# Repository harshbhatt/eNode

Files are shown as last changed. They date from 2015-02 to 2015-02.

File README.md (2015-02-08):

# Notes
* Some resistors and capacitors (imported from the photon) don't have a "box" silkscreen in their footprint - for the final batch, these footprints are better omitted.
* RF components have been placed using the photon as reference
  * (X,Y) coords for RF components have been taken from reference design then moved as a group to maintain relative positioning
* (X,Y) coords for the remaining major components can be referenced from V2
* Make sure to use the 4-layer DRC from spark (under photon\cam-drc\spark-4layer.dru)
* Keep all traces at **12mils** unless absolutely needed

# To-Do
* Change MEMs mic to Condenser mic
* Ground plane vias for RF
* Determine good location for RGB LED
* Copy keepout & fill polygons from V2.2 and photon reference
* Source a SMT LDR?
* All remaining RLC footprints can be replaced with the footprints used by spark, or the master library can be updated

* Possibly shorten overall length of sensor -> if all components fit

# General Guide
* Don't commit library, board and schematic backup files auto generated by Eagle (should be taken care of, by the included .gitignore file, but just fyi)
* Look at V2.2 & photon for reference (Under reference drawings folder)
* Make sure you set your library path to the `Libraries` folder under `Options->Directories` in Eagle

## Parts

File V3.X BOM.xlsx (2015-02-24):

Revision: 3.0 | Project: SenSing V3.1 | Date Revised: | 2015-02-20
Sub-System | Description & Link | Designator | Package / Case | Value & Tol | Manufacturer | Manufacturer P/N | Supplier | Supplier Code | Units /Piece | Unit Price | Total Price /Piece | Total Quantity | Total Price | Notes
Power & Charging | 1800 mAh Li-Po Battery (https://www.sparkfun.com/products/12895) |  |  |  |  |  | Data Power |  | 1 | $2.700 | $2.70 | 80000 | $216000.00 | USD Conv.
 | 3.3v LDO (http://sg.element14.com/richtek/rt9183-33gg/ic-ldo-fixed-3-3v-1-5a-sot-223/dp/2363116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) |  |  |  |  |  | Element14 | 2363116 | 1 | $0.380 | $0.38 | 80000 | $30400.00
 | MCP73831T (Charging) (http://sg.element14.com/jsp/search/productdetail.jsp?id=1332158) |  |  |  |  |  |  |  | 1 | $0.430 | $0.43 | 80000 | $34400.00
 | Micro USB (http://sg.element14.com/jsp/search/productdetail.jsp?SKU=1568026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) |  |  |  |  |  | Element14 | 1568026 | 0 | $0.693 | $0.00 | 0 | $0.00
 | ALT SMD Micro USB (http://sg.element14.com/webapp/wcs/stores/servlet/ProductDisplay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) |  |  |  |  |  | Element14 | 1847433 | 1 | $0.685 | $0.69 | 80000 | $54800.00
 | 4.7 uF (http://sg.element14.com/murata/grm155r60j475me47d/cap-mlcc-x5r-4-7uf-6-3v-0402/dp/2426952) |  | 402 |  |  |  | Element14 | 2426952 | 2 | $0.169 | $0.34 | 160000 | $27040.00
 | 2K OHM (http://sg.element14.com/vishay-draloric/crcw06032k00fkea/product-range-vishay-crcw-series/dp/1469764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) |  | 603 |  |  |  | Element14 | 1469764 | 1 | $0.009 | $0.01 | 80000 | $720.00
 | 100 OHM (http://sg.element14.com/yageo-phycomp/rc0603jr-07100rl/resistor-rc21-0603-100r/dp/9233253) |  | 603 |  |  |  | Element14 | 9233253 | 1 | $0.001 | $0.001 | 80000 | $80.00
 | Indicator LED SMT (http://sg.element14.com/kingbright/ka-2810asursk/led-smd-2-8-x-0-8mm-side-view-red/dp/2146470) |  |  |  |  |  | Element14 | 2146470 | 1 | $0.297 | $0.30 | 80000 | $23760.00
 | JST Header 2-way SMT (http://sg.element14.com/jst-japan-solderless-terminals/s2b-ph-sm4-tb-lf-sn/connector-header-smt-r-a-2mm-2way/dp/9492615) |  |  |  |  |  | Element14 | 9492615 | 1 | $0.832 | $0.83 | 80000 | $66560.00
 |  |  |  |  |  |  |  |  |  |  |  | 0
Current Sensor | INA 219 (http://www.digikey.sg/product-detail/en/INA219AIDCNR/296-23770-1-ND/1952550) |  |  |  |  |  |  |  | 1 | $0.860 | $0.86 | 80000 | $68800.00
 | 0.1 uF (0402) (http://sg.element14.com/multicomp/mc0402x104k100ct/cap-mlcc-x5r-100nf-10v-0402/dp/1759380RL) |  | 402 |  |  |  | Element14 | 1759380RL | 1 | $0.003 | $0.003 | 80000 | $240.00
 | 0.1ohm 1 % (http://www.digikey.sg/product-detail/en/PT2512FK-070R1L/311-0.1ARDKR-ND/2178416) |  | 2512 |  |  |  | Digikey | 311-0.1ARDKR-ND | 0 | $0.440 | $0.00 | 0 | $0.00
 | 0.1 OHM 1% (http://sg.element14.com/panasonic-electronic-components/erj1trsfr10u/resistor-2512-1w-1-0r1/dp/1717945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) |  | 2512 |  |  |  | Element14 | 1717945 | 1 | $0.341 | $0.34 | 80000 | $27280.00
Main PCB components | BM-09 (http://sg.element14.com/jsp/search/productdetail.jsp?sku=1469748RL) |  |  |  |  |  | EDOM/USI |  | 1 | $8.910 | $8.91 | 80000 | $712800.00 | USD Conv.
 | 10K OHM 1% (http://sg.element14.com/jsp/search/productdetail.jsp?sku=1469748RL) |  | 603 |  |  |  | Element14 | 1469748RL | 2 | $0.004 | $0.01 | 160000 | $640.00
 | User Button (http://sg.element14.com/te-connectivity-alcoswitch/fsm4jsmatr/switch-tactile-spst-50ma-smd-outside/dp/2410652) |  |  |  |  |  | Element14 | 2410652 | 2 | $0.183 | $0.37 | 160000 | $29280.00
 | Mode & Reset Button (http://sg.element14.com/multicomp/dtsm-32s-b/switch-spno-0-05a-12v-smd/dp/9471898?ost=DTSM-3) |  |  |  |  |  | Element14 | 9471898 | 2 | $0.254 | $0.51 | 160000 | $40640.00
 | Switch (http://sg.element14.com/eao/09-10290-01/switch-slide-spdt-co-500ma-thd/dp/674357) |  |  |  |  |  | Element14 | 1634623 | 1 | $2.150 | $2.15 | 80000 | $172000.00
 | 4.7K OHM 1% (http://sg.element14.com/multicomp/mc00625w040214k7/resistor-4k7-0-063w-1-0402/dp/1358060) |  | 402 |  |  |  | Element14 | 1358060 | 2 | $0.002 | $0.004 | 160000 | $320.00
 | RGB LED (http://sg.element14.com/cree/clv1l-fkb-chmmqehbb7673673/led-red-green-blue-plcc-4/dp/2414451) |  |  |  |  |  | Element14 | 2414451 | 1 | $0.300 | $0.30 | 80000 | $24000.00
 | Chip Antenna (http://www.digikey.sg/product-detail/en/2450AT43B100E/712-1010-2-ND/1560681) |  |  |  |  |  | Digikey | 712-1010-2-ND | 1 | $0.331 | $0.33 | 80000 | $26462.40
 | 0.8pF RF CAP (http://www.digikey.sg/product-detail/en/GJM1555C1HR80BB01D/490-6080-2-ND/2593264) |  |  |  |  |  | Digikey | 490-6080-2-ND | 1 | $0.034 | $0.03 | 80000 | $2685.60
 | 3.3nH RF IND |  |  |  |  |  | MFG: Hong Kong SUNLORD Co.,Ltd. | PN: HCI1005F-3N3J | 1 |  | $0.00 | 80000 | $0.00
 | 1K OHM (http://sg.element14.com/multicomp/mc00625w040211k/resistor-1k-0-063w-1-0402-reel/dp/2130354) |  |  |  |  |  | Element14 | 2130354 | 4 | $0.002 | $0.01 | 320000 | $576.00
 |  |  |  |  |  |  |  |  |  |  |  | 0
SD | Micro SD Card Slot (http://sg.element14.com/global-connector-technology/mem2051-00-195-00-a/connector-memory-card-micro-sd/dp/2143377) |  |  |  |  |  |  |  | 1 | $0.550 | $0.55 | 80000 | $44000.00
 | Micro SD Card 8GB |  |  |  |  |  | Local Shop |  | 1 | $5.000 | $5.00 | 80000 | $400000.00
IMU | MPU 9150 |  |  |  |  |  |  |  | 1 | $4.710 | $4.71 | 80000 | $376800.00
 | 0.1 uF (0402) (http://sg.element14.com/multicomp/mc0402x104k100ct/cap-mlcc-x5r-100nf-10v-0402/dp/1759380RL) |  | 402 |  |  |  | Element14 | 1759380RL | 2 | $0.003 | $0.01 | 160000 | $480.00
 | 10nF (0.01uF) (http://sg.element14.com/tdk/c1005x7r1e103k050bb/capacitor-ceramic-0-01uf-25v-x7r/dp/1844133?Ntt=1844133) |  | 402 |  |  |  | Element14 | 1844133 | 1 | $0.065 | $0.07 | 80000 | $5200.00
 | 2.2nF (2200pF) (http://sg.element14.com/murata/grm155r71h222ka01d/cap-mlcc-x7r-2-2nf-50v-0402/dp/1828884) |  | 402 |  |  |  | Element14 | 1828884 | 1 | $0.010 | $0.01 | 80000 | $800.00
 |  |  |  |  |  |  |  |  |  |  |  | 0
LDR | LDR - Alt (http://www.digikey.sg/product-search/en?k=+Photo+Light+Dependent+Resistors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) |  |  |  |  |  | Digikey |  | 1 | $0.488 | $0.49 | 80000 | $39040.00
 | 10K OHM 1% (http://sg.element14.com/jsp/search/productdetail.jsp?sku=1469748RL) |  | 603 |  |  |  | Element14 | 1469748RL | 1 | $0.004 | $0.004 | 80000 | $320.00
Mic | Electret Mic |  |  |  | Challenge Electronics | CEM-C9745JAD462P2.54R | Sparkfun | COM-08635 | 1 | $0.675 | $0.68 | 80000 | $54000.00 | Usd Conv. - Changed from MEMs to electret condenser MIC - Calibration tool: http://www.ebay.ca/itm/Mini-Digital-LCD-Audio-Sound-Noise-Level-Meter-Tester-30-130dB-Decibel-Pressure-/271660773561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 - Double check alt sensitivity before using
 | Electret Mic Alt (http://www.digikey.sg/product-detail/en/CMA-4544PF-W/102-1721-ND/1869981) |  |  |  |  |  | Digikey | 102-1721-ND | 0 | $1.340 | $0.00 | 0 | $0.00
 | OPA344 Opamp (http://sg.element14.com/texas-instruments/opa344na-250/ic-op-amp-1mhz-0-8v-us-sot-23-5/dp/9547550) |  |  |  |  |  | Element14 | 9547550 | 1 | $1.010 | $1.01 | 80000 | $80800.00
 | 10K OHM 1% (http://sg.element14.com/jsp/search/productdetail.jsp?sku=1469748RL) |  | 402 | 10K ±1% |  |  | Element14 | 1469748RL | 3 | $0.004 | $0.01 | 240000 | $960.00
 | 2.2K (Pull-Up) (http://sg.element14.com/yageo-phycomp/rc0402jr-072k2l/resistor-rc31-0402-2k2/dp/9232800RL) |  | 402 | 2.2K ±1% |  |  | Element14 | 9232800RL | 1 | $0.001 | $0.001 | 80000 | $80.00
 | 1M (http://sg.element14.com/susumu/rr1220p-105-d/resistor-thin-film-1mohm-100mw/dp/9369716) |  | 402 | 1M ±1% |  |  | Element14 | 9369716 | 1 | $0.014 | $0.01 | 80000 | $1120.00
 | 12pF (http://sg.element14.com/multicomp/mc0402n120k500ct/capacitor-ceramic-12pf-50v-c0g/dp/1709787) |  | 402 | 12pF ±5% |  |  | Element14 | 1709787 | 1 | $0.005 | $0.01 | 80000 | $400.00
 | 4.7 uF (http://sg.element14.com/murata/grm155r60j475me47d/cap-mlcc-x5r-4-7uf-6-3v-0402/dp/2426952) |  | 402 | 4.7uF ±10% |  |  | Element14 | 1759452 | 1 | $0.028 | $0.03 | 80000 | $2240.00
 | 1.0 uF (0603) (http://sg.element14.com/jsp/search/productdetail.jsp?sku=1288256) |  | 402 | 1.0uF ±10% |  |  | Element14 | 1288256 | 1 | $0.013 | $0.01 | 80000 | $1040.00
 | 0.1 uF (0402) (http://sg.element14.com/multicomp/mc0402x104k100ct/cap-mlcc-x5r-100nf-10v-0402/dp/1759380RL) |  | 402 | 0.1uF ±10% |  |  | Element14 | 1759380RL | 1 | $0.003 | $0.003 | 80000 | $240.00
Humidity & Temperature | HTU21D (http://sg.element14.com/measurement-specialties/htu21d/humidity-digital-3-rh-dfn-6/dp/2393536?Ntt=HTU21D) |  |  |  |  |  |  |  | 1 | $3.210 | $3.21 | 80000 | $256800.00
 | 0.1 uF (0402) (http://sg.element14.com/multicomp/mc0402x104k100ct/cap-mlcc-x5r-100nf-10v-0402/dp/1759380RL) |  | 402 |  |  |  | Element14 | 1759380RL | 1 | $0.003 | $0.003 | 80000 | $240.00
Barometer | BMP180 (http://www.mouser.sg/ProductDetail/Bosch-Sensortec/BMP180/?qs=sGAEpiMZZMsrChSOYEGTCcbpL13VfRyojs5HQb1tBiU%3d) |  |  |  |  |  |  | 262-BMP180 | 1 | $1.180 | $1.18 | 80000 | $94400.00
 | BMP180 Alt (https://www.sparkfun.com/products/11823) |  |  |  |  |  | Sparkfun |  | 0 | $6.683 | $0.00 | 0 | $0.00
 | 10uF Tant (http://sg.element14.com/jsp/search/productdetail.jsp?sku=2333009) |  | 1206 |  |  |  | Element14 | 2333009 | 1 | $0.379 | $0.38 | 80000 | $30320.00
 | 0.1 uF (0402) (http://sg.element14.com/multicomp/mc0402x104k100ct/cap-mlcc-x5r-100nf-10v-0402/dp/1759380RL) |  | 402 |  |  |  | Element14 | 1759380RL | 2 | $0.003 | $0.01 | 160000 | $480.00
 |  |  |  |  |  |  |  |  |  |  |  | 0
IR Temperature | TMP007 (http://www.digikey.sg/product-detail/en/TMP007AIYZFT/296-37914-1-ND/4900960) |  |  |  |  |  | Digikey | 296-28819-2-ND | 1 | $5.000 | $5.00 | 80000 | $400000.00
 | 10K OHM 1% (http://sg.element14.com/jsp/search/productdetail.jsp?sku=1469748RL) |  | 603 |  |  |  | Element14 | 1469748RL | 3 | $0.004 | $0.01 | 240000 | $960.00
 | 0.1 uF (0402) (http://sg.element14.com/multicomp/mc0402x104k100ct/cap-mlcc-x5r-100nf-10v-0402/dp/1759380RL) |  | 402 |  |  |  | Element14 | 1759380RL | 1 | $0.003 | $0.003 | 80000 | $240.00
 |  |  |  |  |  |  |  |  |  |  |  | 0
 |  |  |  |  |  |  |  |  |  |  |  | 0
Buzzer | 14mm DIA Buzzer |  |  |  |  |  | Adafruit |  | 1 | $1.282 | $1.28 | 80000 | $102600.00 | USD Conv.
 |  |  |  |  |  |  |  |  |  |  |  | 0
Camera | TTL Camera |  |  |  |  |  |  |  | 1 | $14.850 | $14.85 | 80000 | $1188000.00 | USD Conv
Additional components
Programming Board
 |  |  | Projected Prices |  |  |  |  |  | Total: | $58.01 |  | $4641044.00 | All prices in SGD | USD Conv. Rate
 |  |  |  |  |  |  |  |  |  | /unit | Units: | 80000 |  | 1.35

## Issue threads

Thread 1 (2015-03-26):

GND via shorting RST line

kennethlimcp, 2015-03-26:
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

Closed 2015-04-05.

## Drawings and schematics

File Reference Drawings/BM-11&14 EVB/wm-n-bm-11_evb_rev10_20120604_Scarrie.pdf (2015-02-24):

D | D

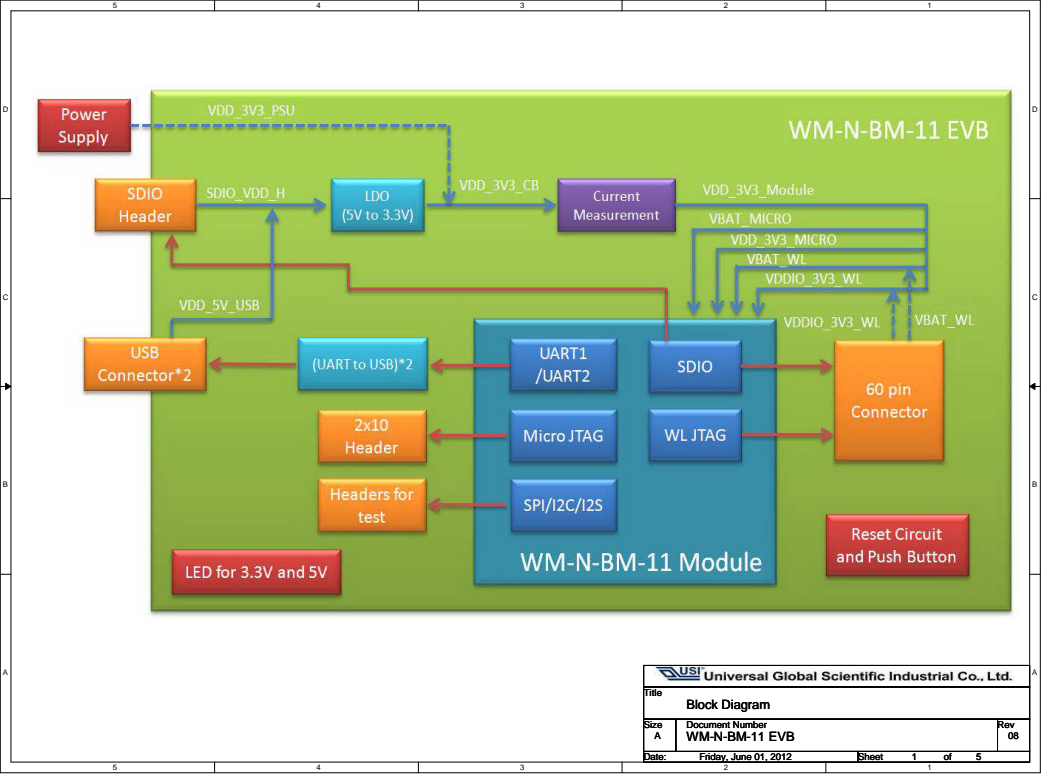
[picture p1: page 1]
Title; Size; Document Number; Rev; Date:; Sheet; WM-N-BM-11 EVB; Block Diagram; Friday, June 01, 2012

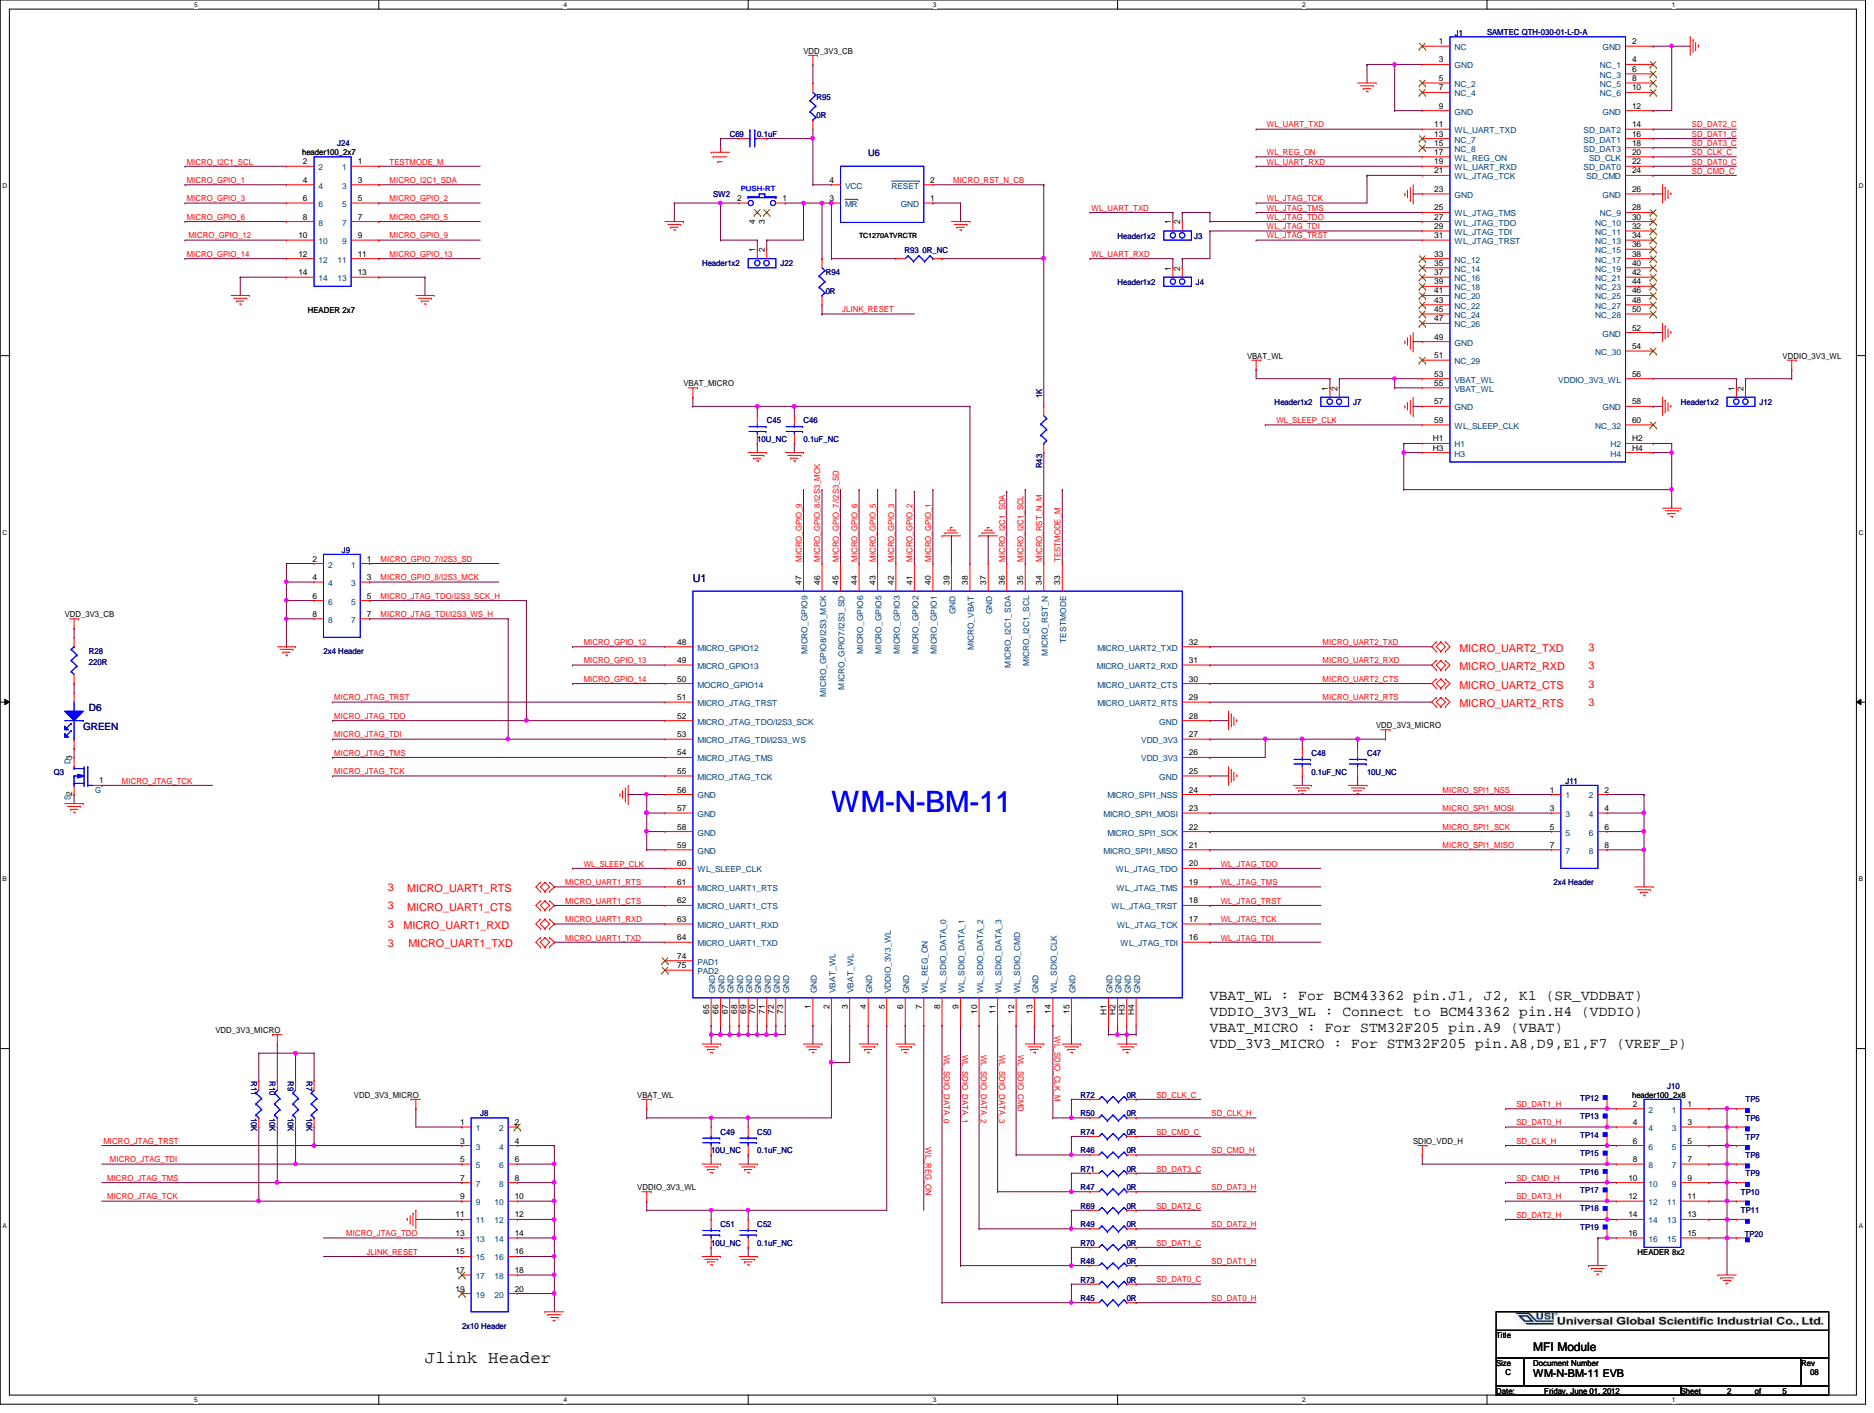
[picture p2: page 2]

VBAT_WL : For BCM43362 pin.J1, J2, K1 (SR_VDDBAT)
VDDIO_3V3_WL : Connect to BCM43362 pin.H4 (VDDIO)
VBAT_MICRO : For STM32F205 pin.A9 (VBAT)
VDD_3V3_MICRO : For STM32F205 pin.A8,D9,E1,F7 (VREF_P)

## RXD1_FT232

## TXD1_FT232

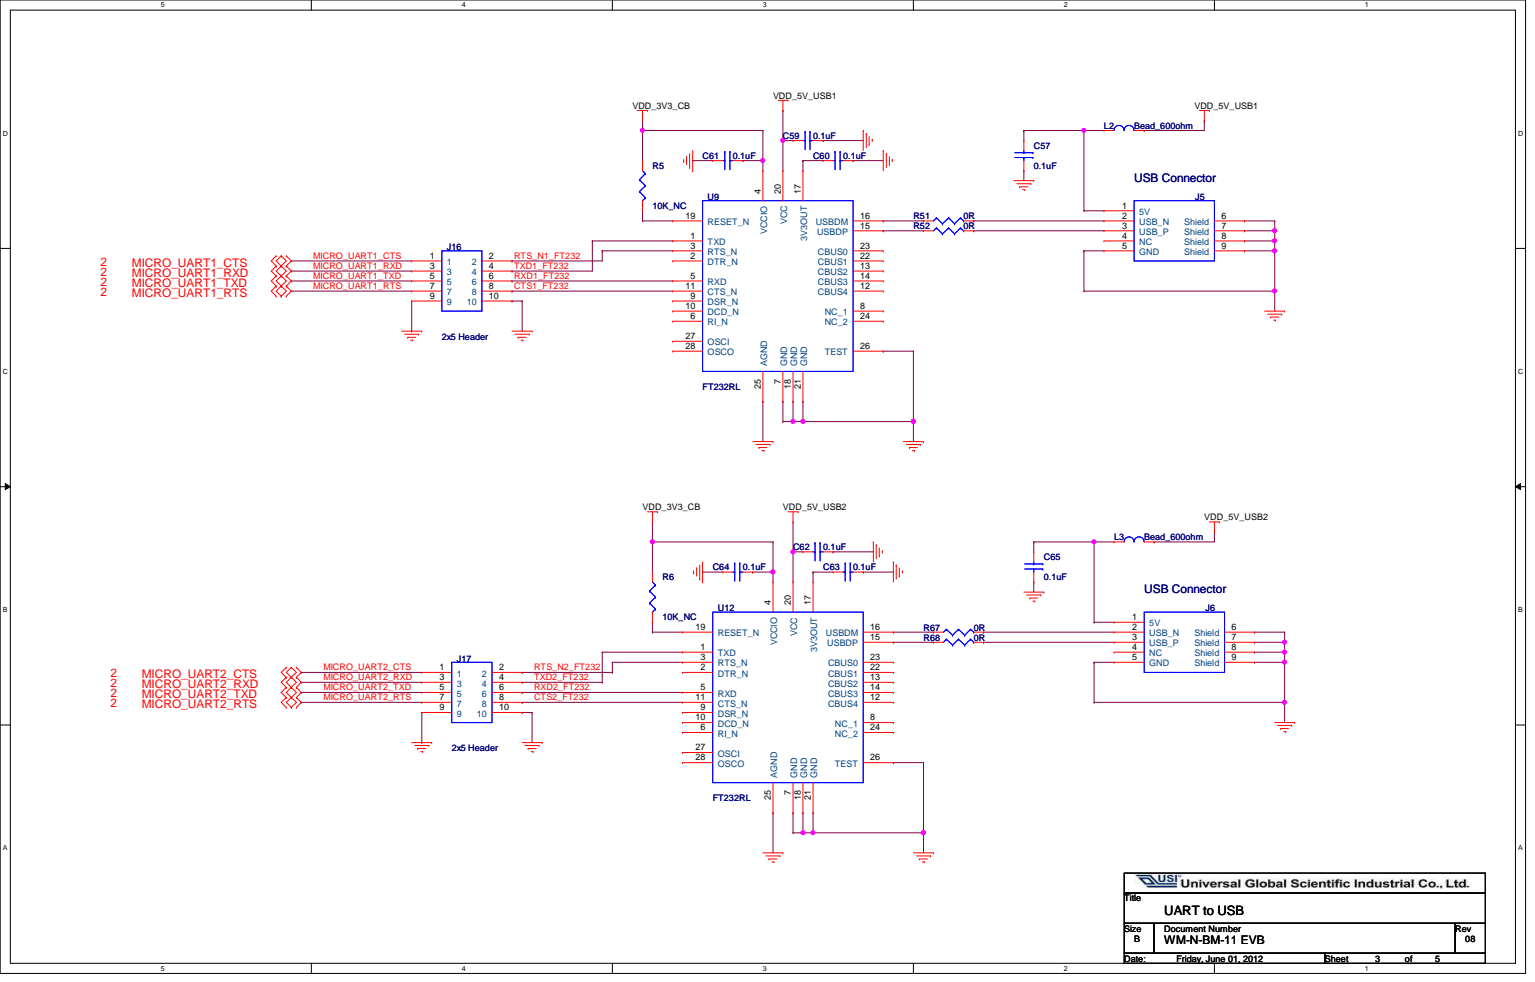
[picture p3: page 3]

# JR4 jumper setting

# Pin1-2: Power is provided from USB

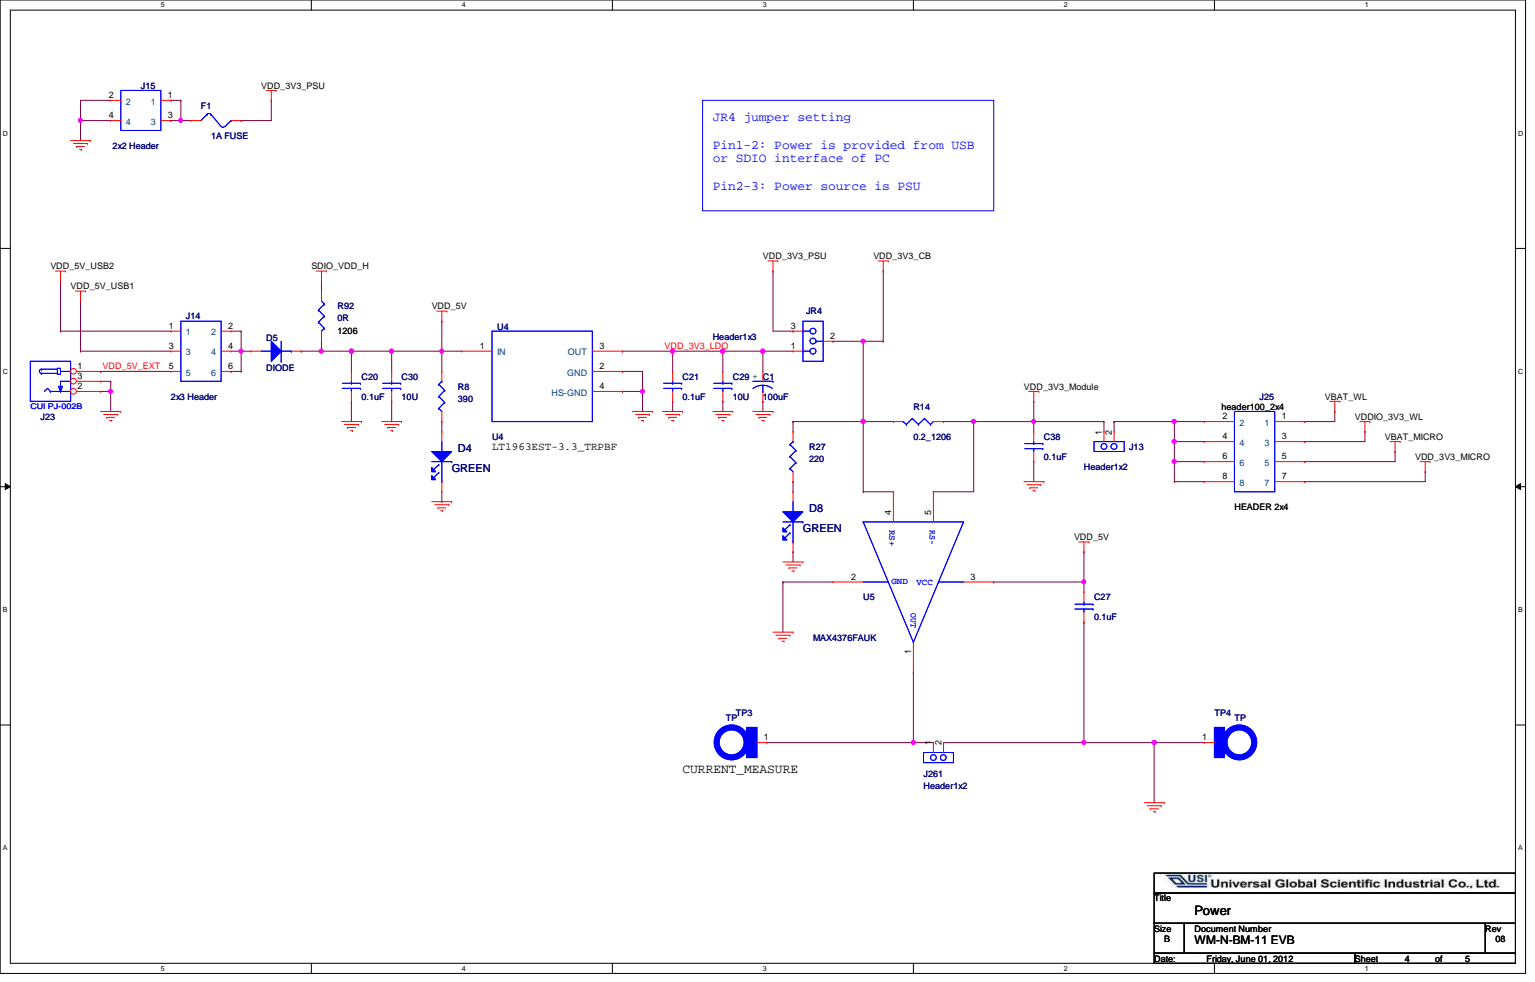
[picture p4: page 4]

or SDIO interface of PC

Pin2-3: Power source is PSU

# Revision History

# 1) Rev. 01 - (2012/03/05)

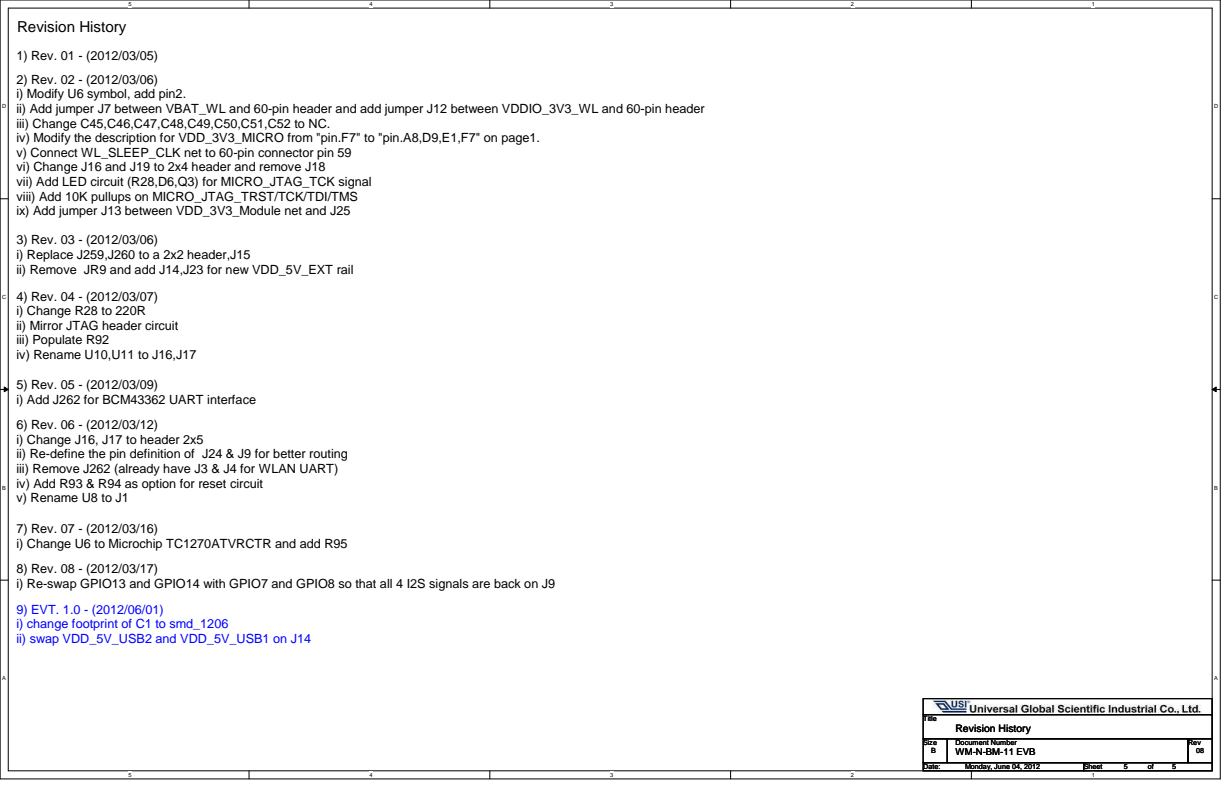
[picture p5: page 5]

2) Rev. 02 - (2012/03/06)
i) Modify U6 symbol, add pin2.
ii) Add jumper J7 between VBAT_WL and 60-pin header and add jumper J12 between VDDIO_3V3_WL and 60-pin header
iii) Change C45,C46,C47,C48,C49,C50,C51,C52 to NC.
iv) Modify the description for VDD_3V3_MICRO from "pin.F7" to "pin.A8,D9,E1,F7" on page1.
v) Connect WL_SLEEP_CLK net to 60-pin connector pin 59
vi) Change J16 and J19 to 2x4 header and remove J18
vii) Add LED circuit (R28,D6,Q3) for MICRO_JTAG_TCK signal
viii) Add 10K pullups on MICRO_JTAG_TRST/TCK/TDI/TMS
ix) Add jumper J13 between VDD_3V3_Module net and J25

3) Rev. 03 - (2012/03/06)
i) Replace J259,J260 to a 2x2 header,J15
ii) Remove JR9 and add J14,J23 for new VDD_5V_EXT rail
4) Rev. 04 - (2012/03/07)
i) Change R28 to 220R
ii) Mirror JTAG header circuit
iii) Populate R92
iv) Rename U10,U11 to J16,J17

5) Rev. 05 - (2012/03/09)
i) Add J262 for BCM43362 UART interface
6) Rev. 06 - (2012/03/12)
i) Change J16, J17 to header 2x5
ii) Re-define the pin definition of J24 & J9 for better routing
iii) Remove J262 (already have J3 & J4 for WLAN UART)
iv) Add R93 & R94 as option for reset circuit
v) Rename U8 to J1

7) Rev. 07 - (2012/03/16)
i) Change U6 to Microchip TC1270ATVRCTR and add R95
8) Rev. 08 - (2012/03/17)
i) Re-swap GPIO13 and GPIO14 with GPIO7 and GPIO8 so that all 4 I2S signals are back on J9
9) EVT. 1.0 - (2012/06/01)
i) change footprint of C1 to smd_1206
ii) swap VDD_5V_USB2 and VDD_5V_USB1 on J14

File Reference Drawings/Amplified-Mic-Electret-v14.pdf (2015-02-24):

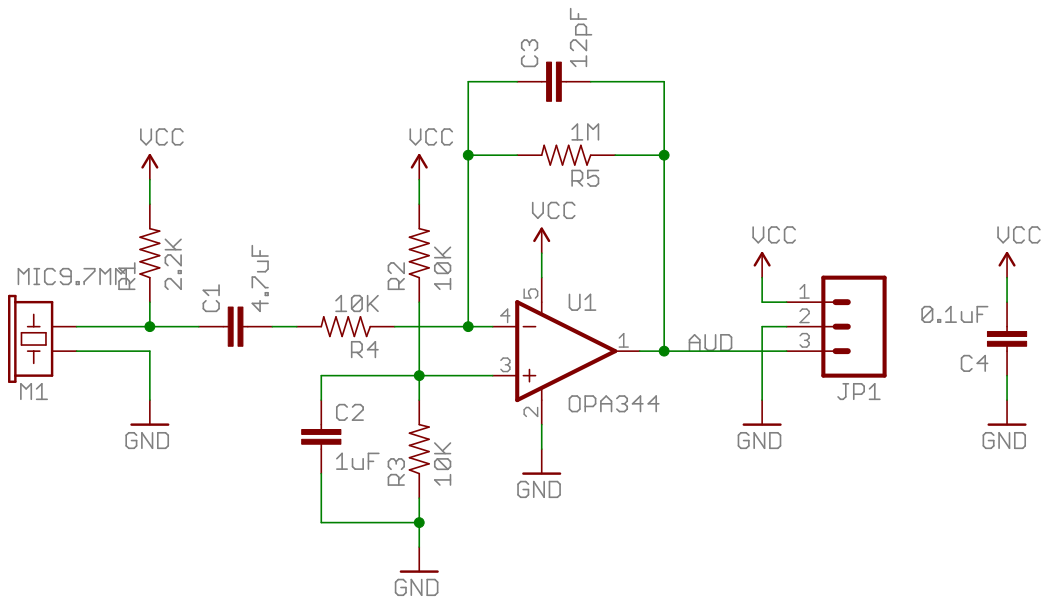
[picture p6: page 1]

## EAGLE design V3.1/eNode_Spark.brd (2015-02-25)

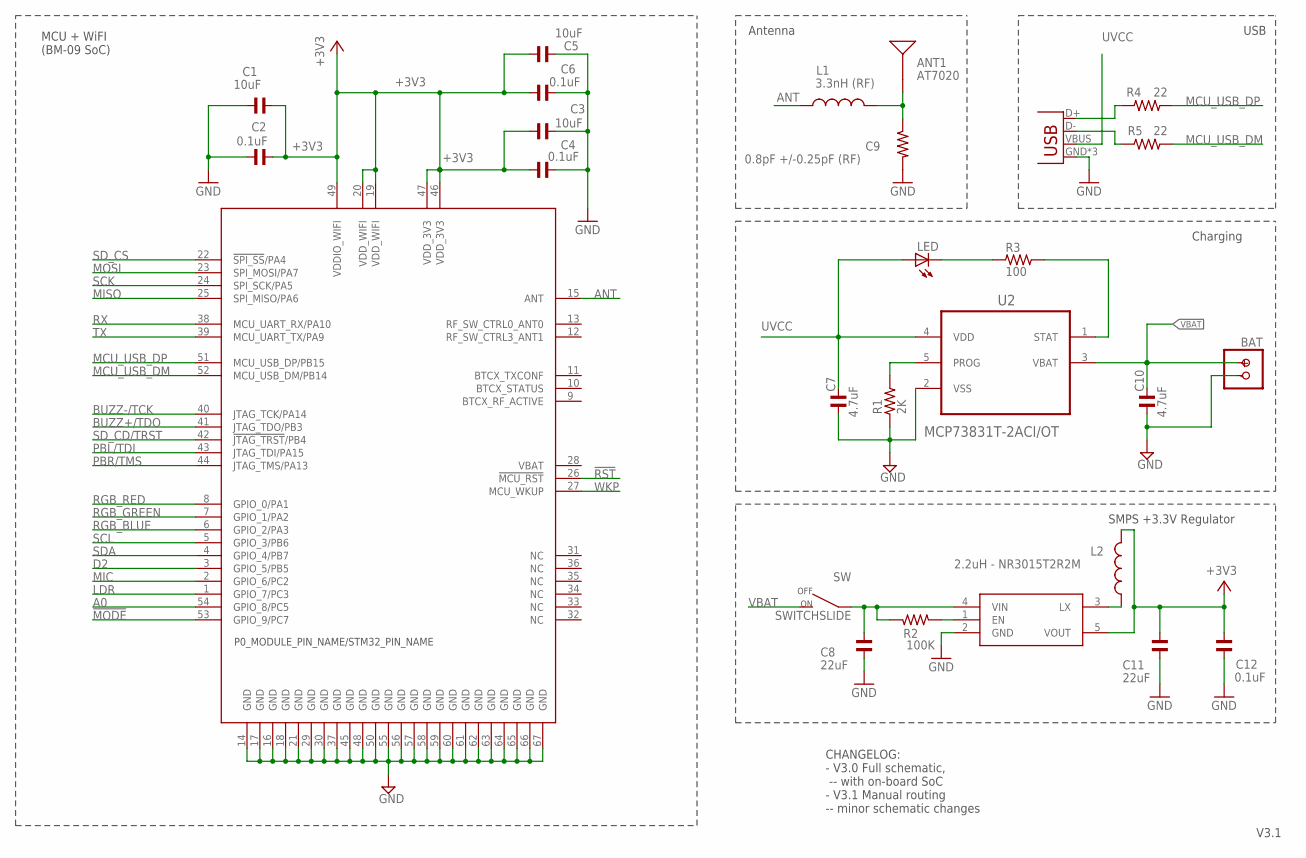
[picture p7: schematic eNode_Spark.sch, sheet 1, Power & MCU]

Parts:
ANT1: AT7020
BAT: BATTERYSMT; JST-2-SMD
C1, C3, C5: 10uF; C0402
C2, C4, C6, C12: 0.1uF; C0402
C7, C10: 4.7uF; C0402
C8, C11: 22uF; C0603
C9: 0.8pF +/-0.25pF (RF); R0402_B
L1: 3.3nH (RF); L0402_B
L2: 2.2uH - NR3015T2R2M; INDUCTOR-NR3015
LED: LED; RA_SMD_LED
R1: 2K; R0603
R2: 100K; R0402
R3: 100; R0603
R4, R5: 22; R0402
SW: SWITCHSLIDE; CHANGE_OVER_SLIDE
U1: WM-N-BM-09
U2: MCP73831T-2ACI/OT; SOT95P280X145-5N
U3: R8008-33; SOT23-5
X1: USB-MICROB; USB-MICROB-SLOT-HOLE

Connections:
!MODE: U1.53 (GPIO_9/PC7); also elsewhere on the board
!RST: U1.26 (!MCU_RST); also elsewhere on the board
+3V3: C1.2, C2.2, C3.1, C4.2, C5.1, C6.2, C11.1, C12.1, L2.2, U1.19 (VDD_WIFI), U1.20 (VDD_WIFI), U1.46 (VDD_3V3), U1.47 (VDD_3V3), U1.49 (VDDIO_WIFI), U3.5 (VOUT); also elsewhere on the board
A0: U1.54 (GPIO_8/PC5)
ANT: L1.1, U1.15 (ANT)
BUZZ+/TDO: U1.41 (JTAG_TDO/PB3); also elsewhere on the board
BUZZ-/TCK: U1.40 (JTAG_TCK/PA14); also elsewhere on the board
D2: U1.3 (GPIO_5/PB5)
ENABLE: R2.1, U3.1 (EN)
GND: BAT.-, C1.1, C2.1, C3.2, C4.1, C5.2, C6.1, C7.1, C8.2, C9.2, C10.1, C11.2, C12.2, R1.1, U1.14 (GND), U1.16 (GND), U1.17 (GND), U1.18 (GND), U1.21 (GND), U1.29 (GND), U1.30 (GND), U1.37 (GND), U1.45 (GND), U1.48 (GND), U1.50 (GND), U1.55 (GND), U1.56 (GND), U1.57 (GND), U1.58 (GND), U1.59 (GND), U1.60 (GND), U1.61 (GND), U1.62 (GND), U1.63 (GND), U1.64 (GND), U1.65 (GND), U1.66 (GND), U1.67 (GND), U2.2 (VSS), U3.2 (GND), X1.GND, X1.MT1 (GND), X1.MT2 (GND); also elsewhere on the board
LDR: U1.1 (GPIO_7/PC3); also elsewhere on the board
MCU_USB_DM: R5.1, U1.52 (MCU_USB_DM/PB14)
MCU_USB_DP: R4.1, U1.51 (MCU_USB_DP/PB15)
MIC: U1.2 (GPIO_6/PC2); also elsewhere on the board
MISO: U1.25 (SPI_MISO/PA6); also elsewhere on the board
MOSI: U1.23 (SPI_MOSI/PA7); also elsewhere on the board
unnamed: ANT1.1, C9.1, L1.2
unnamed: C8.1, R2.2, SW.1, U3.4 (VIN)
unnamed: L2.1, U3.3 (LX)
unnamed: R1.2, U2.5 (PROG)
unnamed: LED.C, R3.1
unnamed: R3.2, U2.1 (STAT)
unnamed: R5.2, X1.D-
unnamed: R4.2, X1.D+
PBL/TDI: U1.43 (JTAG_TDI/PA15); also elsewhere on the board
PBR/TMS: U1.44 (JTAG_TMS/PA13); also elsewhere on the board
RGB_BLUE: U1.6 (GPIO_2/PA3); also elsewhere on the board
RGB_GREEN: U1.7 (GPIO_1/PA2); also elsewhere on the board
RGB_RED: U1.8 (GPIO_0/PA1); also elsewhere on the board
RX: U1.38 (MCU_UART_RX/PA10); also elsewhere on the board
SCK: U1.24 (SPI_SCK/PA5); also elsewhere on the board
SCL: U1.5 (GPIO_3/PB6); also elsewhere on the board
SDA: U1.4 (GPIO_4/PB7); also elsewhere on the board
SD_CD/TRST: U1.42 (!JTAG_TRST!/PB4); also elsewhere on the board
SD_CS: U1.22 (!SPI_SS!/PA4); also elsewhere on the board
TX: U1.39 (MCU_UART_TX/PA9); also elsewhere on the board
UVCC: C7.2, LED.A, U2.4 (VDD), X1.VBUS
VBAT: BAT.+, C10.2, SW.2, U2.3 (VBAT)
WKP: U1.27 (MCU_WKUP)

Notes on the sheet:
CHANGELOG: - V3.0 Full schematic, -- with on-board SoC - V3.1 Manual routing -- minor schematic changes
USB
MCU + WiFI (BM-09 SoC)
Charging
Antenna
SMPS +3.3V Regulator

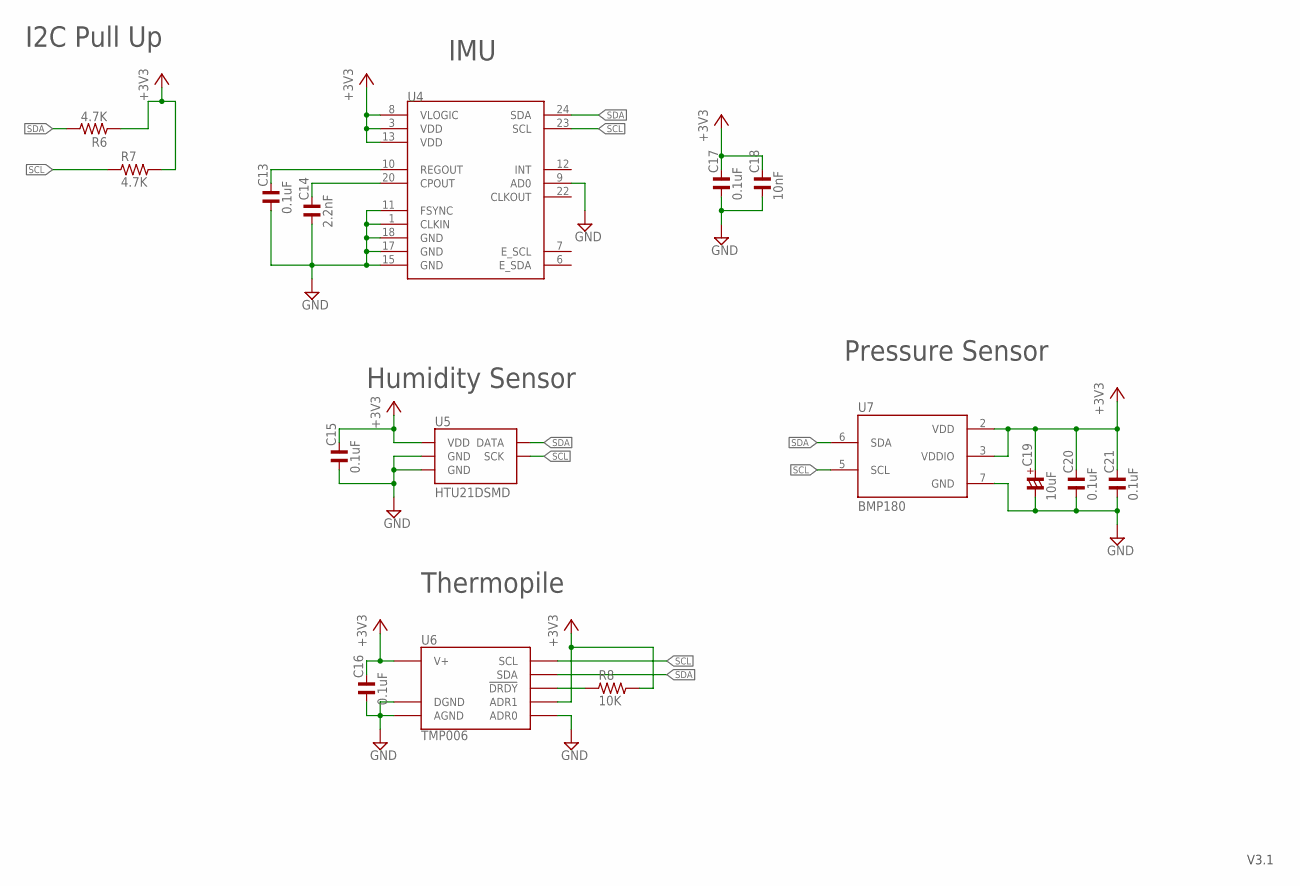
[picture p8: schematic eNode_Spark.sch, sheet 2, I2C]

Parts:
C13, C15, C16, C17, C20, C21: 0.1uF; C0402
C14: 2.2nF; C0402
C18: 10nF; C0402
C19: 10uF; C1206/T
R6, R7: 4.7K; R0402
R8: 10K; R0603
U4: MPU-9150QFN-24-NP; QFN-24-NP
U5: HTU21DSMD; HTU21D
U6: TMP006; BGA8DS
U7: BMP180

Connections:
+3V3: C15.2, C16.2, C17.2, C18.2, C19.+, C20.2, C21.2, R6.1, R7.2, R8.2, U4.3 (VDD), U4.8 (VLOGIC), U4.13 (VDD), U5.VDD, U6.A3 (V+), U6.B1 (ADR1), U7.2 (VDD), U7.3 (VDDIO); also elsewhere on the board
GND: C13.1, C14.1, C15.1, C16.1, C17.1, C18.1, C19.-, C20.1, C21.1, U4.1 (CLKIN), U4.9 (AD0), U4.11 (FSYNC), U4.15 (GND), U4.17 (GND), U4.18 (GND), U5.7 (GND), U5.GND, U6.A1 (DGND), U6.A2 (AGND), U6.C1 (ADR0), U7.7 (GND); also elsewhere on the board
unnamed: C14.2, U4.20 (CPOUT)
unnamed: R8.1, U6.C2 (!DRDY)
unnamed: C13.2, U4.10 (REGOUT)
SCL: R7.1, U4.23 (SCL), U5.SCK, U6.B3 (SCL), U7.5 (SCL); also elsewhere on the board
SDA: R6.2, U4.24 (SDA), U5.DATA, U6.C3 (SDA), U7.6 (SDA); also elsewhere on the board

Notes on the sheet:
IMU
Humidity Sensor
Pressure Sensor
Thermopile
I2C Pull Up

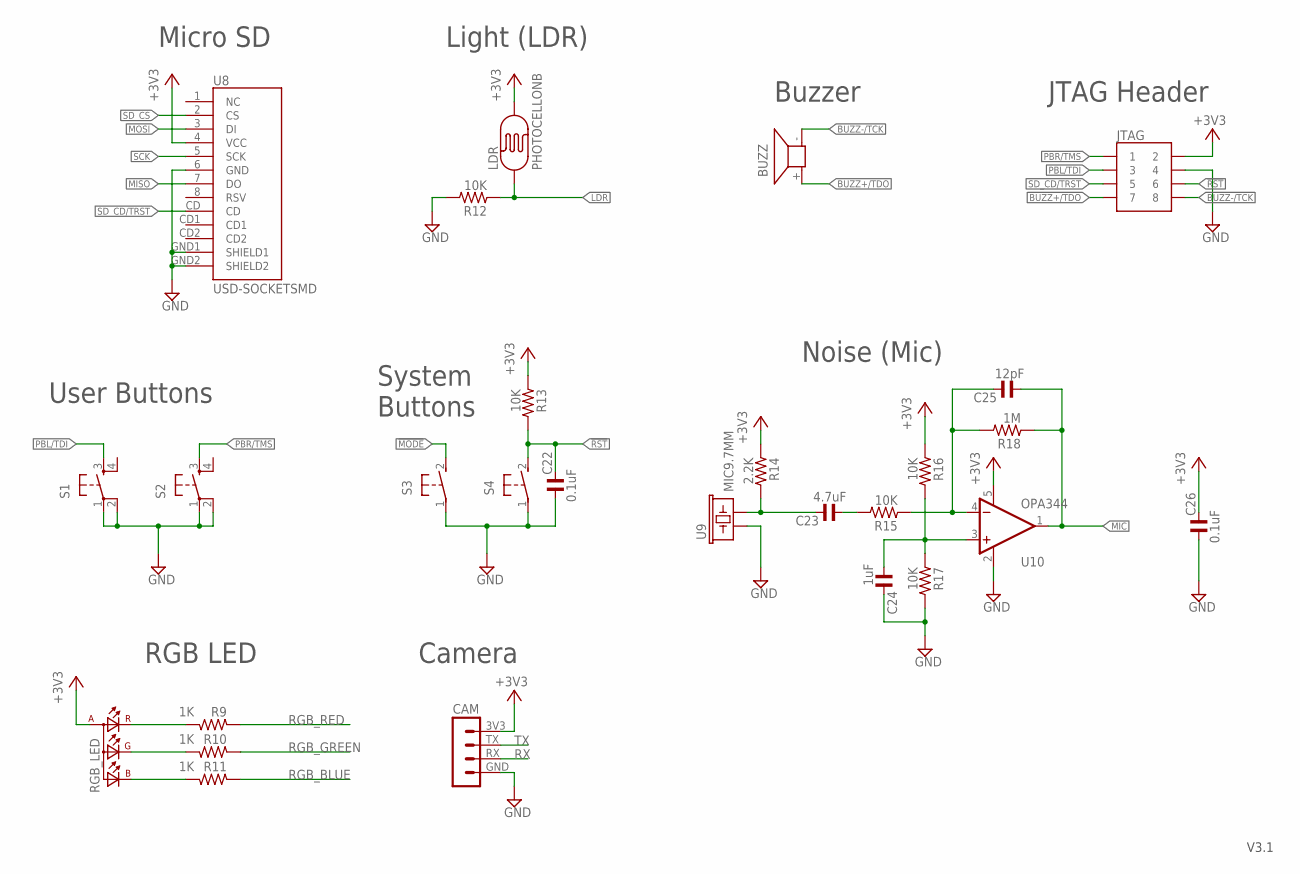
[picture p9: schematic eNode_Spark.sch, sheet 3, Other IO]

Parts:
BUZZ: BUZZER; OFFBOARD_NOSIGN
C22, C26: 0.1uF; C0402
C23: 4.7uF; C0402
C24: 1uF; C0402
C25: 12pF; C0402
CAM: MA04-1
JTAG: JTAG_CONNECTOR; JTAG_DIP
LDR: PHOTOCELLONB; ON_BOARD
R9, R10, R11: 1K; R0402
R12: 10K; R0603
R13, R15, R16, R17: 10K; R0402
R14: 2.2K; R0402
R18: 1M; R0402
RGB_LED: TOPLED-3PLCC; P-LCC-4-3
S1, S2: TAC_SWITCH_4SMD; TACTILE_SWITCH_SMD_LARGE_4
S3: MODE; DTSM-3
S4: RESET; DTSM-3
U8: USD-SOCKETSMD; MICRO-SD-SOCKET-PP
U9: MIC9.7MM; MIC-9.7MM
U10: OPA344; SOT23-5

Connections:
!MODE: S3.2; also elsewhere on the board
!RST: C22.2, JTAG.6, R13.2, S4.2; also elsewhere on the board
+3V3: C26.2, CAM.3V3, JTAG.2, LDR.2, R13.1, R14.1, R16.1, RGB_LED.A (A2), U8.4 (VCC), U10.5 (V+); also elsewhere on the board
BUZZ+/TDO: BUZZ.+, JTAG.7; also elsewhere on the board
BUZZ-/TCK: BUZZ.-, JTAG.8; also elsewhere on the board
GND: C22.1, C24.2, C26.1, CAM.GND, JTAG.4, R12.2, R17.2, S1.1, S1.2, S2.1, S2.2, S3.1, S4.1, U8.6 (GND), U8.GND1 (SHIELD1), U8.GND2 (SHIELD2), U9.1, U10.2 (V-); also elsewhere on the board
LDR: LDR.1, R12.1; also elsewhere on the board
MIC: C25.1, R18.1, U10.1 (OUT); also elsewhere on the board
MISO: U8.7 (DO); also elsewhere on the board
MOSI: U8.3 (DI); also elsewhere on the board
unnamed: C23.1, R15.2
unnamed: C25.2, R15.1, R18.2, U10.4 (-IN)
unnamed: C24.1, R16.2, R17.1, U10.3 (+IN)
unnamed: C23.2, R14.2, U9.2
unnamed: R10.1, RGB_LED.G (CGREEN)
unnamed: R11.1, RGB_LED.B (CBLUE)
unnamed: R9.1, RGB_LED.R (CRED)
PBL/TDI: JTAG.3, S1.3; also elsewhere on the board
PBR/TMS: JTAG.1, S2.3; also elsewhere on the board
RGB_BLUE: R11.2; also elsewhere on the board
RGB_GREEN: R10.2; also elsewhere on the board
RGB_RED: R9.2; also elsewhere on the board
RX: CAM.RX; also elsewhere on the board
SCK: U8.5 (SCK); also elsewhere on the board
SD_CD/TRST: JTAG.5, U8.CD; also elsewhere on the board
SD_CS: U8.2 (CS); also elsewhere on the board
TX: CAM.TX; also elsewhere on the board

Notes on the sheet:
Micro SD
User Buttons
Light (LDR)
Buzzer
Noise (Mic)
RGB LED
Camera
System Buttons
JTAG Header

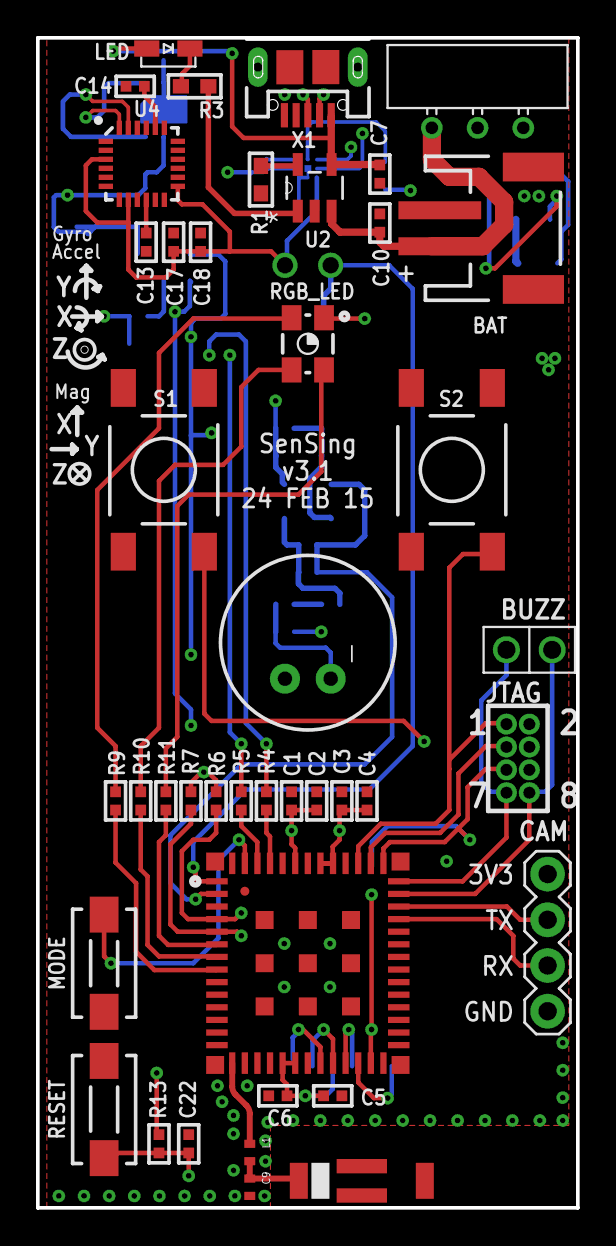
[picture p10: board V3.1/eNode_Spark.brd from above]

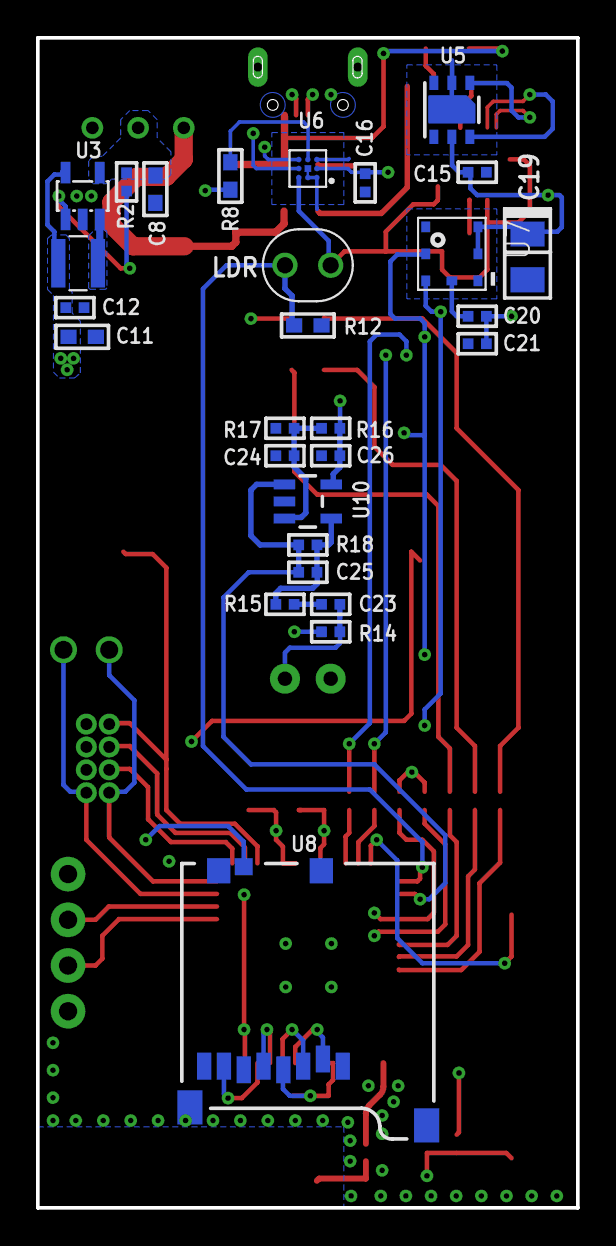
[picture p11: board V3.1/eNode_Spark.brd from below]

Board: 4 copper layers, 30.0 x 65.0 mm, 70 parts (28 on the bottom side), 46 nets.

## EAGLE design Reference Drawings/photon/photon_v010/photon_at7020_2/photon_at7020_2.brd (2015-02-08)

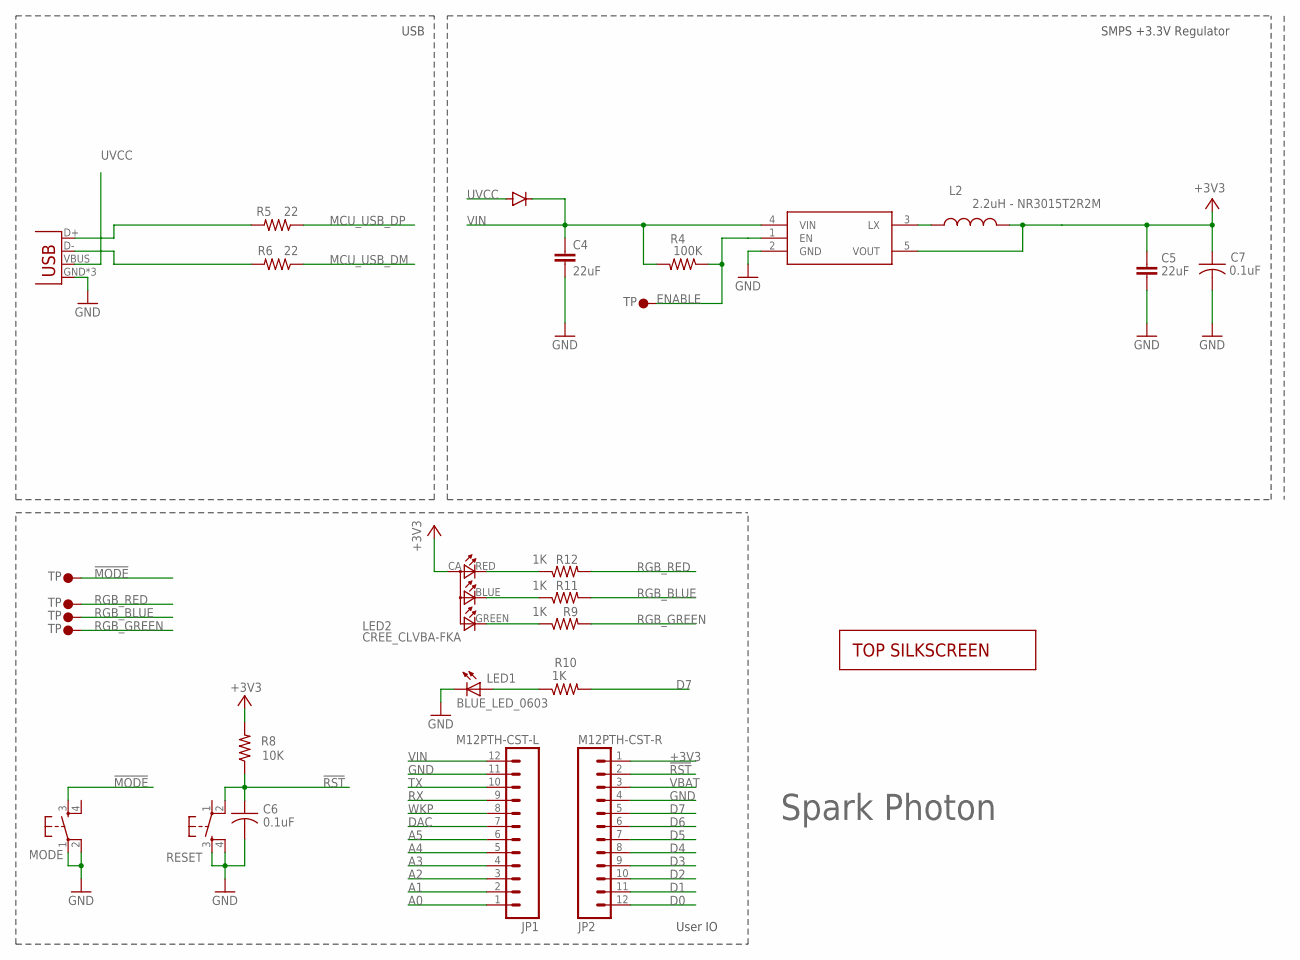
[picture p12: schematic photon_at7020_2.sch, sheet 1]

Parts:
BLUE_LED_0603: LED0603; LED-0603
C4, C5: 22uF; C0603
C6: 0.1uF; C0402_B
C7: 0.1uF; C0402
D1: DIODE; DIODE-DO-220AA(SMP)
JP1: M12PTH-CST-L; 1X12-CASTELLATED
JP2: M12PTH-CST-R; 1X12-CASTELLATED
L2: 2.2uH - NR3015T2R2M; INDUCTOR-NR3015
LED2: CREE_CLVBA-FKA; PLCC4-2MM-RGB
MODE: KMR211GLFS; TACTILE_SWITCH_SMD
R4: 100K; R0402_B
R5, R6: 22; R0402_B
R8: 10K; R0402_B
R9, R10, R11, R12: 1K; R0402_B
RESET: KMR211GLFS; TACTILE_SWITCH_SMD
U$1: PHOTON-TOP-SS
U$3, U$5, U$6, U$7, U$12: TP1; TP35_BOT
U$11: R8008-33; SOT23-5
X1: USB-MICROB; USB-MICROB-SLOT-HOLE

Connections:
!MODE: MODE.3, U$3.P$1; also elsewhere on the board
!RST: C6.1, JP2.2, R8.1, RESET.2; also elsewhere on the board
+3V3: C5.1, C7.1, JP2.1, L2.2, LED2.CA (A2), R8.2, U$11.5 (VOUT); also elsewhere on the board
A0: JP1.1 (12); also elsewhere on the board
A1: JP1.2 (11); also elsewhere on the board
A2: JP1.3 (10); also elsewhere on the board
A3: JP1.4 (9); also elsewhere on the board
A4: JP1.5 (8); also elsewhere on the board
A5: JP1.6 (7); also elsewhere on the board
D0: JP2.12; also elsewhere on the board
D1: JP2.11; also elsewhere on the board
D2: JP2.10; also elsewhere on the board
D3: JP2.9; also elsewhere on the board
D4: JP2.8; also elsewhere on the board
D5: JP2.7; also elsewhere on the board
D6: JP2.6; also elsewhere on the board
D7: JP2.5, R10.2; also elsewhere on the board
DAC: JP1.7 (6); also elsewhere on the board
ENABLE: R4.1, U$11.1 (EN), U$12.P$1
GND: BLUE_LED_0603.C, C4.2, C5.2, C6.2, C7.2, JP1.11 (2), JP2.4, MODE.1, MODE.2, RESET.3, RESET.4, U$11.2 (GND), X1.GND, X1.MT1 (GND), X1.MT2 (GND); also elsewhere on the board
LED1: BLUE_LED_0603.A, R10.1
MCU_USB_DM: R6.1; also elsewhere on the board
MCU_USB_DP: R5.1; also elsewhere on the board
unnamed: R5.2, X1.D+
unnamed: L2.1, U$11.3 (LX)
unnamed: R6.2, X1.D-
unnamed: LED2.BLUE (CBLUE), R11.1
unnamed: LED2.GREEN (CGREEN), R9.1
unnamed: LED2.RED (CRED), R12.1
RGB_BLUE: R11.2, U$6.P$1; also elsewhere on the board
RGB_GREEN: R9.2, U$7.P$1; also elsewhere on the board
RGB_RED: R12.2, U$5.P$1; also elsewhere on the board
RX: JP1.9 (4); also elsewhere on the board
TX: JP1.10 (3); also elsewhere on the board
UVCC: D1.ANODE, X1.VBUS
VBAT: JP2.3; also elsewhere on the board
VIN: C4.1, D1.CATHODE, JP1.12 (1), R4.2, U$11.4 (VIN)
WKP: JP1.8 (5); also elsewhere on the board

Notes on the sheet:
SMPS +3.3V Regulator
User IO
USB
Spark Photon

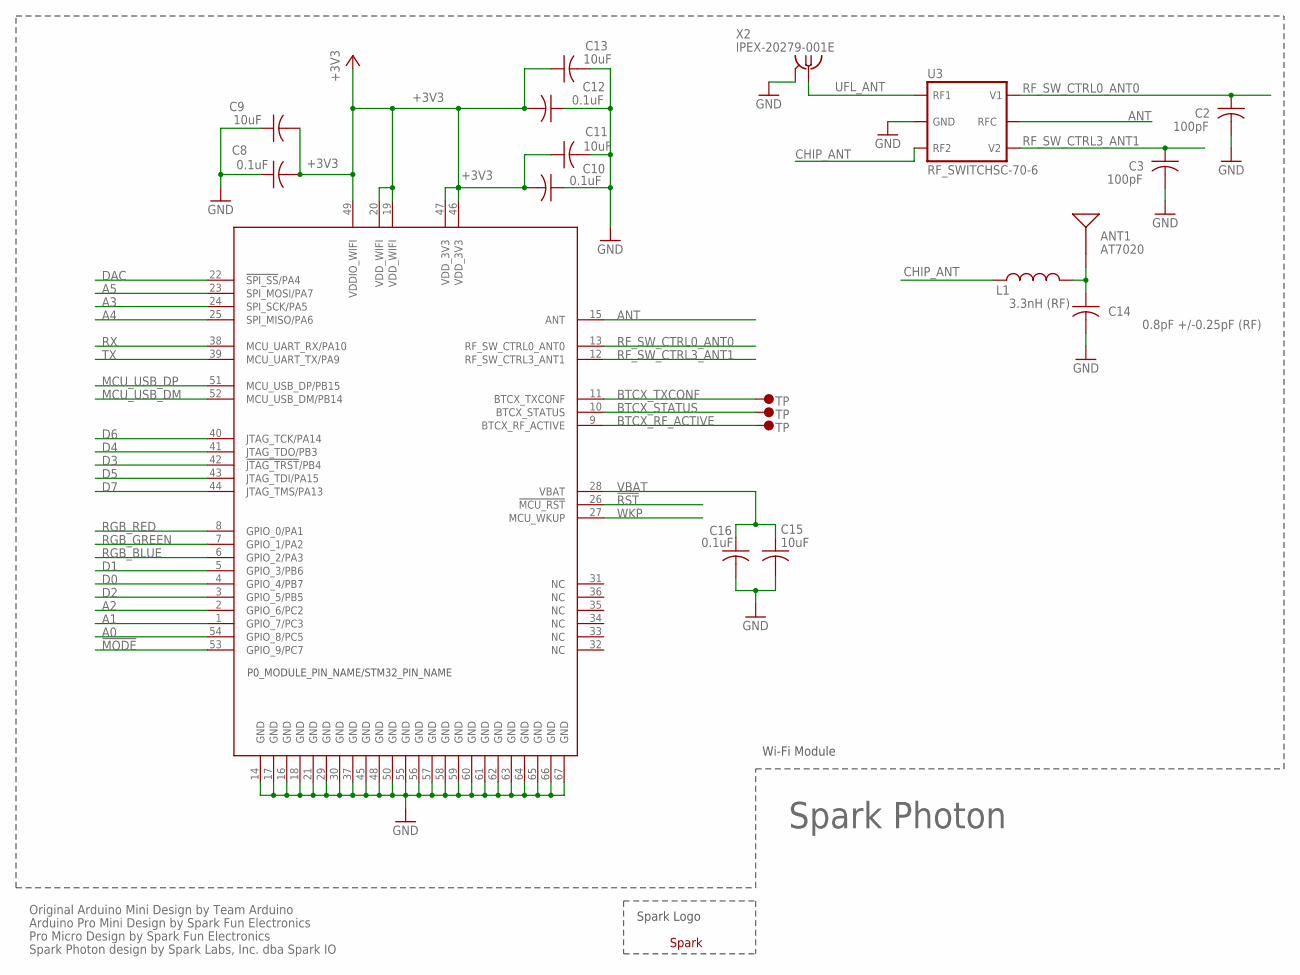
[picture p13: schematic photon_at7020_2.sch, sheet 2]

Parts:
ANT1: AT7020
C2, C3: 100pF; C0402_B
C8, C10, C12, C16: 0.1uF; C0402_B
C9, C11, C13, C15: 10uF; C0402_B
C14: 0.8pF +/-0.25pF (RF); C0402_B
L1: 3.3nH (RF); L0402_B
U1: WM-N-BM-09
U3: RF_SWITCHSC-70-6; SC70-6
U$2: SPARK_LOGO2
U$8, U$9, U$10: TP1; TP35_BOT
X2: IPEX-20279-001E

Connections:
!MODE: U1.53 (GPIO_9/PC7); also elsewhere on the board
!RST: U1.26 (!MCU_RST); also elsewhere on the board
+3V3: C8.2, C9.2, C10.2, C11.1, C12.2, C13.1, U1.19 (VDD_WIFI), U1.20 (VDD_WIFI), U1.46 (VDD_3V3), U1.47 (VDD_3V3), U1.49 (VDDIO_WIFI); also elsewhere on the board
A0: U1.54 (GPIO_8/PC5); also elsewhere on the board
A1: U1.1 (GPIO_7/PC3); also elsewhere on the board
A2: U1.2 (GPIO_6/PC2); also elsewhere on the board
A3: U1.24 (SPI_SCK/PA5); also elsewhere on the board
A4: U1.25 (SPI_MISO/PA6); also elsewhere on the board
A5: U1.23 (SPI_MOSI/PA7); also elsewhere on the board
ANT: U1.15 (ANT), U3.5 (RFC)
BTCX_RF_ACTIVE: U1.9 (BTCX_RF_ACTIVE), U$10.P$1
BTCX_STATUS: U1.10 (BTCX_STATUS), U$9.P$1
BTCX_TXCONF: U1.11 (BTCX_TXCONF), U$8.P$1
CHIP_ANT: L1.1, U3.3 (RF2)
D0: U1.4 (GPIO_4/PB7); also elsewhere on the board
D1: U1.5 (GPIO_3/PB6); also elsewhere on the board
D2: U1.3 (GPIO_5/PB5); also elsewhere on the board
D3: U1.42 (!JTAG_TRST!/PB4); also elsewhere on the board
D4: U1.41 (JTAG_TDO/PB3); also elsewhere on the board
D5: U1.43 (JTAG_TDI/PA15); also elsewhere on the board
D6: U1.40 (JTAG_TCK/PA14); also elsewhere on the board
D7: U1.44 (JTAG_TMS/PA13); also elsewhere on the board
DAC: U1.22 (!SPI_SS!/PA4); also elsewhere on the board
GND: C2.2, C3.2, C8.1, C9.1, C10.1, C11.2, C12.1, C13.2, C14.2, C15.2, C16.2, U1.14 (GND), U1.16 (GND), U1.17 (GND), U1.18 (GND), U1.21 (GND), U1.29 (GND), U1.30 (GND), U1.37 (GND), U1.45 (GND), U1.48 (GND), U1.50 (GND), U1.55 (GND), U1.56 (GND), U1.57 (GND), U1.58 (GND), U1.59 (GND), U1.60 (GND), U1.61 (GND), U1.62 (GND), U1.63 (GND), U1.64 (GND), U1.65 (GND), U1.66 (GND), U1.67 (GND), U3.2 (GND), X2.2@1 (GND), X2.2@2 (GND); also elsewhere on the board
MCU_USB_DM: U1.52 (MCU_USB_DM/PB14); also elsewhere on the board
MCU_USB_DP: U1.51 (MCU_USB_DP/PB15); also elsewhere on the board
unnamed: ANT1.1, C14.1, L1.2
RF_SW_CTRL0_ANT0: C2.1, U1.13 (RF_SW_CTRL0_ANT0), U3.6 (V1)
RF_SW_CTRL3_ANT1: C3.1, U1.12 (RF_SW_CTRL3_ANT1), U3.4 (V2)
RGB_BLUE: U1.6 (GPIO_2/PA3); also elsewhere on the board
RGB_GREEN: U1.7 (GPIO_1/PA2); also elsewhere on the board
RGB_RED: U1.8 (GPIO_0/PA1); also elsewhere on the board
RX: U1.38 (MCU_UART_RX/PA10); also elsewhere on the board
TX: U1.39 (MCU_UART_TX/PA9); also elsewhere on the board
UFL_ANT: U3.1 (RF1), X2.1
VBAT: C15.1, C16.1, U1.28 (VBAT); also elsewhere on the board
WKP: U1.27 (MCU_WKUP); also elsewhere on the board

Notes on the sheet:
Original Arduino Mini Design by Team Arduino
Arduino Pro Mini Design by Spark Fun Electronics
Pro Micro Design by Spark Fun Electronics
Spark Photon design by Spark Labs, Inc. dba Spark IO
Spark Photon
Wi-Fi Module
Spark Logo

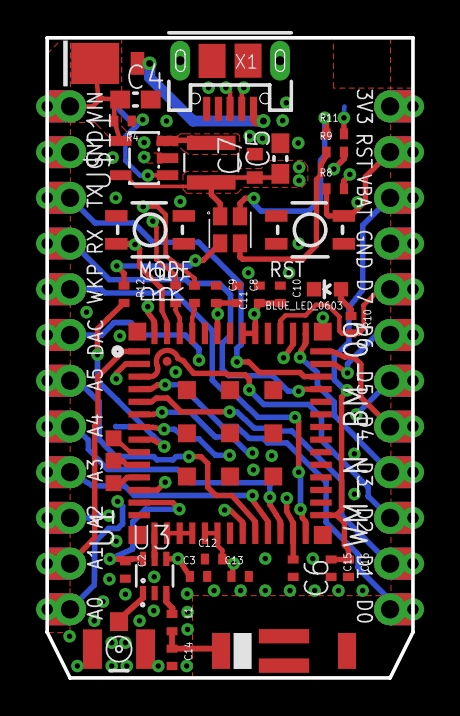
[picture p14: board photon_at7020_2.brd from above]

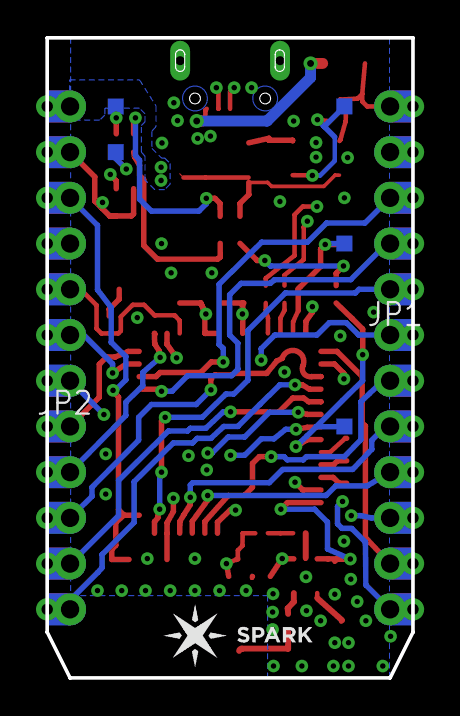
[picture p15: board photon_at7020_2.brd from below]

Board: 4 copper layers, 20.3 x 35.6 mm, 48 parts (5 on the bottom side), 47 nets.

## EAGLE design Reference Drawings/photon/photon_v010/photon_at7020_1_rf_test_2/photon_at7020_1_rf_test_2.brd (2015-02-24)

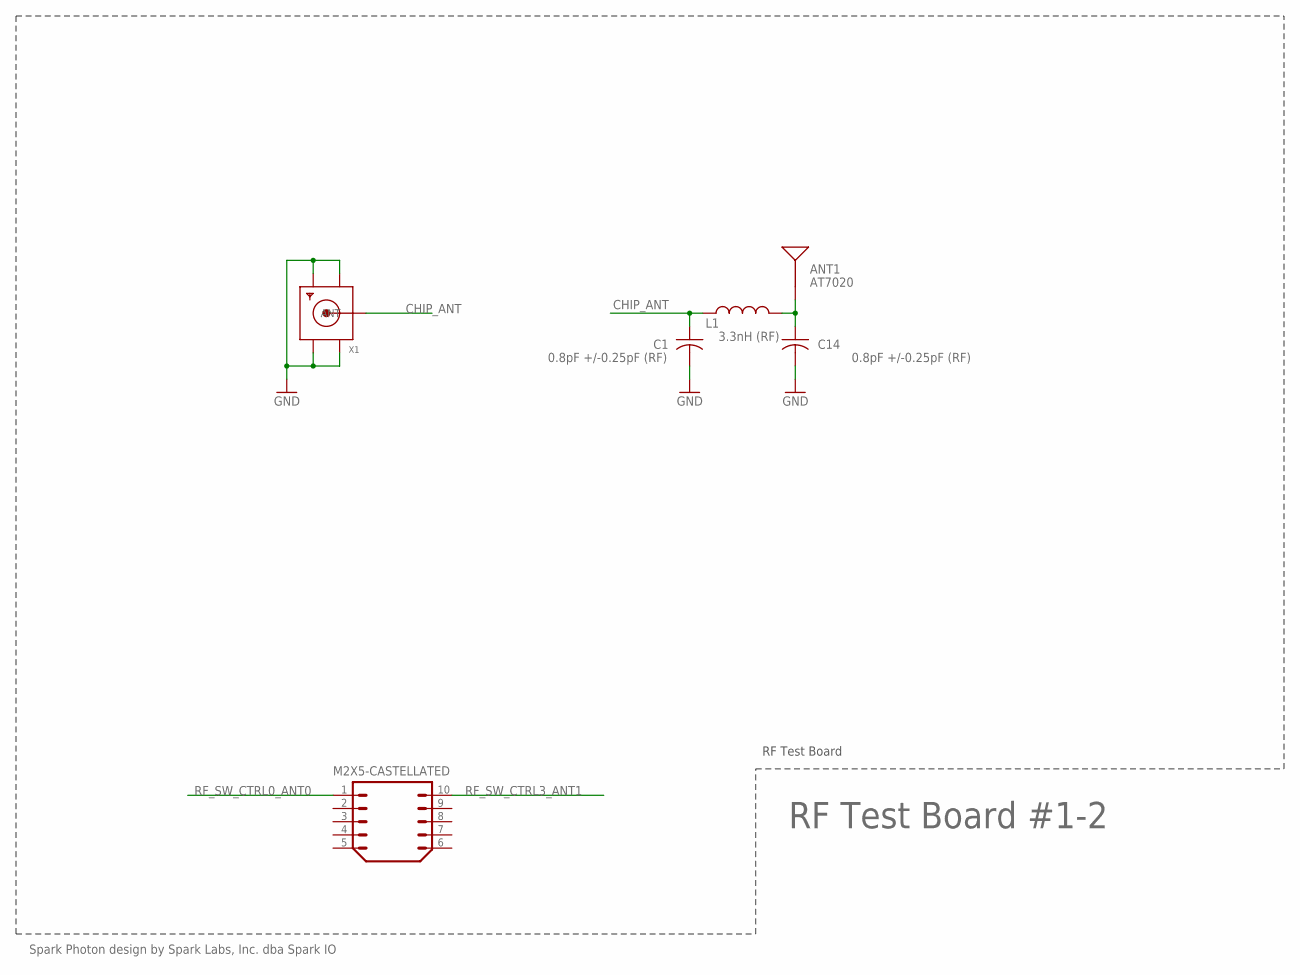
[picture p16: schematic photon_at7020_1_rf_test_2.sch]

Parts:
ANT1: AT7020
C1, C14: 0.8pF +/-0.25pF (RF); C0402_B
L1: 3.3nH (RF); L0402_B
M2X5-CASTELLATED: M2X5; 2X5-CASTELLATED
X1: SMACONNECTOR_EDGE; SMA_EDGELAUNCH

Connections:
CHIP_ANT: C1.1, L1.1, X1.P (ANT)
GND: C1.2, C14.2, X1.GND@1 (GND4), X1.GND@2 (GND3), X1.GND@3 (GND2), X1.GND@4 (GND1)
unnamed: ANT1.1, C14.1, L1.2
RF_SW_CTRL0_ANT0: M2X5-CASTELLATED.1
RF_SW_CTRL3_ANT1: M2X5-CASTELLATED.10

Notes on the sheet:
Spark Photon design by Spark Labs, Inc. dba Spark IO
RF Test Board #1-2
RF Test Board

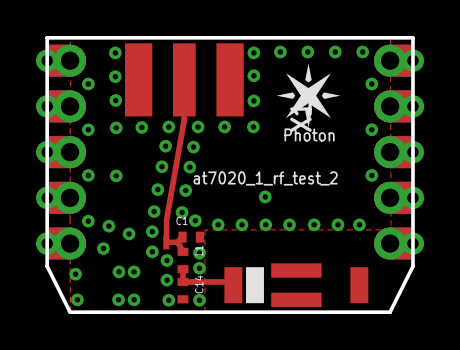
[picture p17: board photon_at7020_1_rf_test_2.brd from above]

Board: 4 copper layers, 20.3 x 15.2 mm, 6 parts (0 on the bottom side), 3 nets.

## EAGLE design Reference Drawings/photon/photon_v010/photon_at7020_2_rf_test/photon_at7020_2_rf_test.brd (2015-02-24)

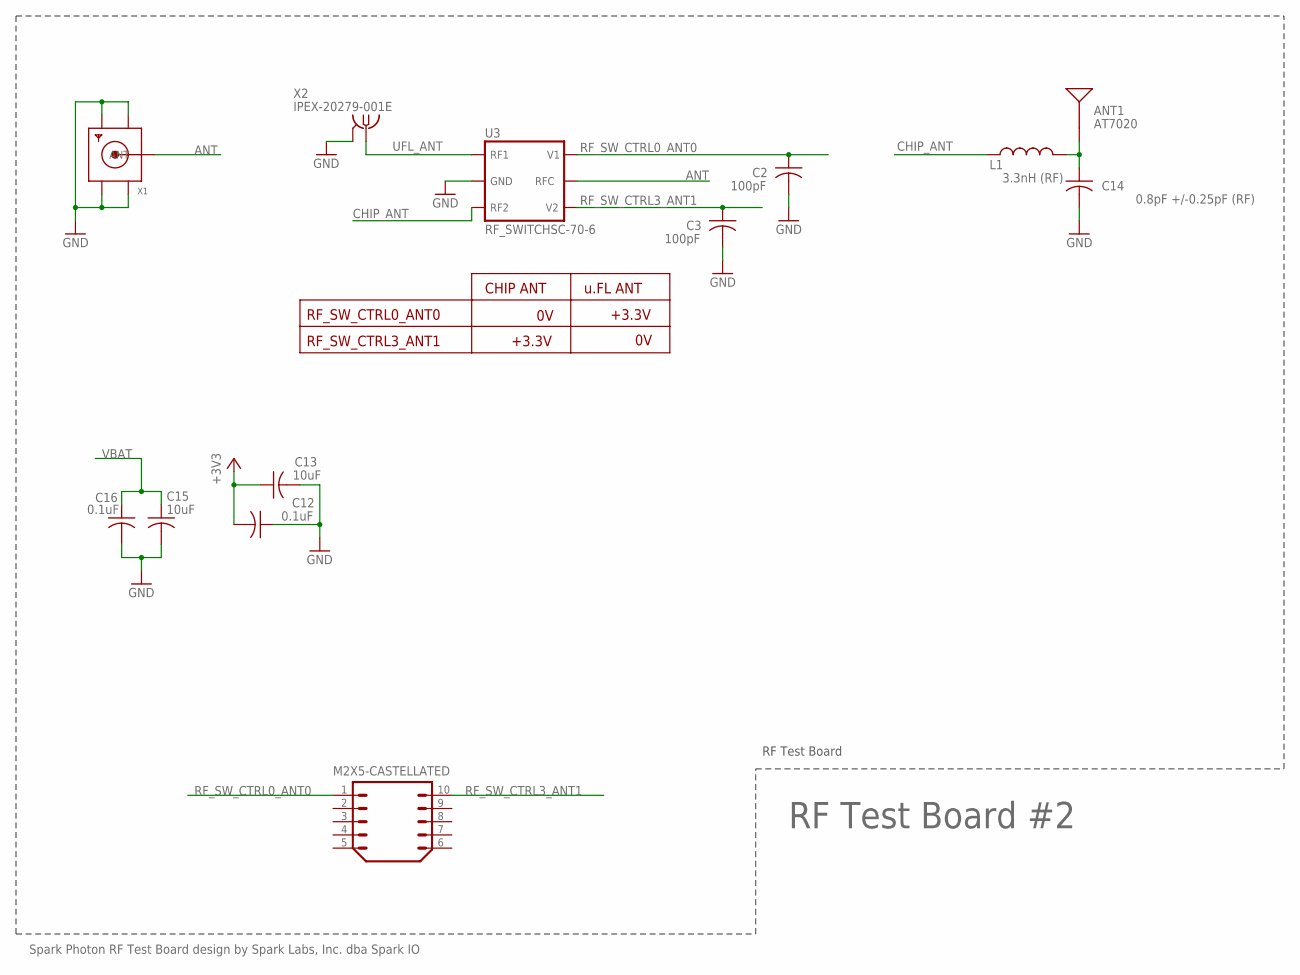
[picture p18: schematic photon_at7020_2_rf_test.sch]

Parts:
ANT1: AT7020
C2, C3: 100pF; C0402_B
C12, C16: 0.1uF; C0402_B
C13, C15: 10uF; C0402_B
C14: 0.8pF +/-0.25pF (RF); C0402_B
L1: 3.3nH (RF); L0402_B
M2X5-CASTELLATED: M2X5; 2X5-CASTELLATED
U3: RF_SWITCHSC-70-6; SC70-6
X1: SMACONNECTOR_EDGE; SMA_EDGELAUNCH
X2: IPEX-20279-001E

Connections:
+3V3: C12.2, C13.1
ANT: U3.5 (RFC), X1.P (ANT)
CHIP_ANT: L1.1, U3.3 (RF2)
GND: C2.2, C3.2, C12.1, C13.2, C14.2, C15.2, C16.2, U3.2 (GND), X1.GND@1 (GND4), X1.GND@2 (GND3), X1.GND@3 (GND2), X1.GND@4 (GND1), X2.2@1 (GND), X2.2@2 (GND)
unnamed: ANT1.1, C14.1, L1.2
RF_SW_CTRL0_ANT0: C2.1, M2X5-CASTELLATED.1, U3.6 (V1)
RF_SW_CTRL3_ANT1: C3.1, M2X5-CASTELLATED.10, U3.4 (V2)
UFL_ANT: U3.1 (RF1), X2.1
VBAT: C15.1, C16.1

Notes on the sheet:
Spark Photon RF Test Board design by Spark Labs, Inc. dba Spark IO
RF Test Board #2
RF Test Board
RF_SW_CTRL0_ANT0
RF_SW_CTRL3_ANT1
+3.3V
CHIP ANT
u.FL ANT


Board: 4 copper layers, 20.3 x 15.2 mm, 13 parts (0 on the bottom side), 9 nets.

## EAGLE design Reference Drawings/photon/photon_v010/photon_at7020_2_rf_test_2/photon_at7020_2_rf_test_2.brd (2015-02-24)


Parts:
ANT1: AT7020
C14: 0.8pF +/-0.25pF (RF); C0402_B
L1: 3.3nH (RF); L0402_B
M2X5-CASTELLATED: M2X5; 2X5-CASTELLATED
X1: SMACONNECTOR_EDGE; SMA_EDGELAUNCH

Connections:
CHIP_ANT: L1.1, X1.P (ANT)
GND: C14.2, X1.GND@1 (GND4), X1.GND@2 (GND3), X1.GND@3 (GND2), X1.GND@4 (GND1)
unnamed: ANT1.1, C14.1, L1.2
RF_SW_CTRL0_ANT0: M2X5-CASTELLATED.1
RF_SW_CTRL3_ANT1: M2X5-CASTELLATED.10

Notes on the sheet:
Spark Photon RF Test Board design by Spark Labs, Inc. dba Spark IO
RF Test Board #2-2
RF Test Board


Board: 4 copper layers, 20.3 x 15.2 mm, 5 parts (0 on the bottom side), 3 nets.

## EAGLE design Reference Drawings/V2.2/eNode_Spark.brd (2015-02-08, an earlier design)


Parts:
BAT: BATTERYSMT; JST-2-SMD
C1, C2: 4.7uF; C0402
C11: 0.1uF; C0402
J1: 47346-0001; MOLEX_47346-0001
LED: LED; RA_SMD_LED
R1: 100; R0603
R2: 2K; R0603
R9, R10: 4.7K; R0603
R11: 0.1; R2512
SPARK: SPARK_CORECORE; SPARK_CORE
SW: SWITCHSLIDE; CHANGE_OVER_SLIDE
U5: INA219; SOT23-8
U6: MCP73831T-2ACI/OT; SOT95P280X145-5N
U$1, U$2, U$6, U$7, U$8, U$9, U$10, U$11, U$12, U$13, U$14, U$15, U$16, U$17: 1PIN

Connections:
+3V3: C11.2, R9.1, R10.1, SPARK.22 (VDDA), U5.4 (VCC), U5.7 (A0), U$6.P$1; also elsewhere on the board
BUZZ+: SPARK.18 (D5); also elsewhere on the board
BUZZ-: SPARK.19 (D6); also elsewhere on the board
GND: BAT.-, C1.1, C2.1, C11.1, J1.5 (GND), R2.1, SPARK.2 (GND), SPARK.21 (GND), U5.3 (GND), U5.8 (A1), U6.2 (VSS), U$11.P$1, U$17.P$1; also elsewhere on the board
LDR: SPARK.11 (A1), U$16.P$1; also elsewhere on the board
MIC: SPARK.6 (A6); also elsewhere on the board
MISO: SPARK.8 (A4); also elsewhere on the board
MOSI: SPARK.7 (A5); also elsewhere on the board
unnamed: C1.2, J1.1 (VCC), LED.A, U6.4 (VDD)
unnamed: R11.1, SPARK.1 (RAW), U5.2 (VIN-)
unnamed: R2.2, U6.5 (PROG)
unnamed: LED.C, R1.1
unnamed: R1.2, U6.1 (STAT)
unnamed: SPARK.5 (A7), U$2.P$1
unnamed: R11.2, SW.2, U5.1 (VIN+)
unnamed: SPARK.20 (D7), U$10.P$1
unnamed: SPARK.12 (A0), U$1.P$1
unnamed: SPARK.3 (TX), U$12.P$1
unnamed: SPARK.4 (RX), U$13.P$1
unnamed: SPARK.23 (!RST), U$14.P$1
PB1: SPARK.15 (D2), U$9.P$1; also elsewhere on the board
PB2: SPARK.16 (D3), U$15.P$1; also elsewhere on the board
SCK: SPARK.9 (A3); also elsewhere on the board
SCL: R9.2, SPARK.14 (D1), U5.5 (SCL), U$7.P$1; also elsewhere on the board
SDA: R10.2, SPARK.13 (D0), U5.6 (SDA), U$8.P$1; also elsewhere on the board
SD_CD: SPARK.17 (D4); also elsewhere on the board
SD_CS: SPARK.10 (A2); also elsewhere on the board
VBAT: BAT.+, C2.2, SW.1, U6.3 (VBAT)
VCC: SPARK.24 (VCC)

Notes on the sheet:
SPARK CORE
Charging
Power Sensor
V2.1.1
CHANGELOG: - V2.1.1: Shifted Spark core up 10 mil


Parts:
C6, C7, C8, C10, C12, C15: 0.1uF; C0402
C9: 10uF; C1206/T
C14: 2.2nF; C0402
C16: 10nF; C0402
R13: 10K; R0603
U2: BMP180
U3: HTU21DSMD; HTU21D
U4: MPU-9150QFN-24-NP; QFN-24-NP
U7: TMP006; BGA8DS

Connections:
+3V3: C6.2, C7.2, C8.2, C9.+, C10.2, C15.2, C16.2, R13.2, U2.2 (VDD), U2.3 (VDDIO), U3.VDD, U4.3 (VDD), U4.8 (VLOGIC), U4.13 (VDD), U7.A3 (V+), U7.B1 (ADR1); also elsewhere on the board
GND: C6.1, C7.1, C8.1, C9.-, C10.1, C12.1, C14.1, C15.1, C16.1, U2.7 (GND), U3.7 (GND), U3.GND, U4.1 (CLKIN), U4.9 (AD0), U4.11 (FSYNC), U4.15 (GND), U4.17 (GND), U4.18 (GND), U7.A1 (DGND), U7.A2 (AGND), U7.C1 (ADR0); also elsewhere on the board
unnamed: C14.2, U4.20 (CPOUT)
unnamed: R13.1, U7.C2 (!DRDY)
unnamed: C12.2, U4.10 (REGOUT)
SCL: U2.5 (SCL), U3.SCK, U4.23 (SCL), U7.B3 (SCL); also elsewhere on the board
SDA: U2.6 (SDA), U3.DATA, U4.24 (SDA), U7.C3 (SDA); also elsewhere on the board

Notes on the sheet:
IMU
Humidity Sensor
Pressure Sensor
Thermopile
V2.1.1


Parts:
BUZZ: BUZZER; OFFBOARD_NOSIGN
C3: 4.7uF; C0402
C4: 100pF; C0402
C5: 1uF; C0402
C13: 0.1uF; C0402
LDR: PHOTOCELLONB; ON_BOARD
PB1, PB2: PB
R4: 1.5K; R0402
R5: 100K; R0402
R6, R7: 10K; R0402
R12, R14, R15: 10K; R0603
U1: USD-SOCKETSMD; MICRO-SD-SOCKET-PP
U8: OPA344; SOT23-5
U9: ADMP401

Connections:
+3V3: C13.2, LDR.2, PB1.2, PB2.2, R7.1, U1.4 (VCC), U8.5 (V+), U9.5 (VDD); also elsewhere on the board
BUZZ+: BUZZ.+; also elsewhere on the board
BUZZ-: BUZZ.-; also elsewhere on the board
GND: C5.2, C13.1, R6.2, R12.2, R14.1, R15.1, U1.6 (GND), U1.GND1 (SHIELD1), U1.GND2 (SHIELD2), U8.2 (V-), U9.2 (GND), U9.4 (GND), U9.6 (GND); also elsewhere on the board
LDR: LDR.1, R12.1; also elsewhere on the board
MIC: C4.1, R5.1, U8.1 (OUT); also elsewhere on the board
MISO: U1.7 (DO); also elsewhere on the board
MOSI: U1.3 (DI); also elsewhere on the board
unnamed: C3.2, U9.1 (OUT)
unnamed: C3.1, R4.2
unnamed: C4.2, R4.1, R5.2, U8.4 (-IN)
unnamed: C5.1, R6.1, R7.2, U8.3 (+IN)
PB1: PB1.1, R14.2; also elsewhere on the board
PB2: PB2.1, R15.2; also elsewhere on the board
SCK: U1.5 (SCK); also elsewhere on the board
SD_CD: U1.CD; also elsewhere on the board
SD_CS: U1.2 (CS); also elsewhere on the board

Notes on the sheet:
Micro SD
Push Buttons
Light (LDR)
Buzzer
Noise (Mic)
V2.1.1



Board: 2 copper layers, 30.0 x 65.0 mm, 61 parts (26 on the bottom side), 35 nets.

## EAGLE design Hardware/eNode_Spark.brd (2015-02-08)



Board: 4 copper layers, 30.0 x 65.0 mm, 65 parts (4 on the bottom side), 43 nets, no tracks yet.

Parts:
ANT1: AT7020
BAT: JST-2-SMD
BUZZ: BUZZER; OFFBOARD_NOSIGN
C1, C2, C3: 4.7uF; C0402
C4: 100pF; C0402
C5: 1uF; C0402
C6, C7, C8, C10, C12, C13, C15, C25: 0.1uF; C0402
C9: 10uF; C1206/T
C11: 0.8pF +/-0.25pF (RF); C0402_B
C14: 2.2nF; C0402
C16: 10nF; C0402
C17, C18, C19: 0.1uF; C0402_B
C20, C21, C22: 10uF; C0402_B
C23, C24: 22uF; C0603
D1: DIODE; DIODE-DO-220AA(SMP)
L1: 3.3nH (RF); L0402_B
L2: 2.2uH - NR3015T2R2M; INDUCTOR-NR3015
LDR: PHOTOCELLONB; ON_BOARD
LED: RA_SMD_LED
LED2: CREE_CLVBA-FKA; P-LCC-4-3
R1: 100; R0603
R2: 2K; R0603
R3, R8: 22; R0402_B
R4: 1.5K; R0402
R5: 100K; R0402
R6, R7: 10K; R0402
R9: 100K; R0402_B
R10, R14, R15: 1K; R0402_B
R11, R16: 4.7K; R0603
R12, R13: 10K; R0603
S1, S2: TACTILE_SWITCH_SMD
SV1: MA04-1
SW: SWITCHSLIDE; CHANGE_OVER_SLIDE
U1: USD-SOCKETSMD; MICRO-SD-SOCKET-PP
U2: BMP180
U3: HTU21DSMD; HTU21D
U4: QFN-24-NP
U6: MCP73831T-2ACI/OT; SOT95P280X145-5N
U7: TMP006; BGA8DS
U8: OPA344; SOT23-5
U9: ADMP401
U10: WM-N-BM-09
U$7: R8008-33; SOT23-5
X1: USB-MICROB; USB-MICROB-SLOT-HOLE

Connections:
+3V3: C6.2, C7.2, C8.2, C9.+, C10.2, C13.2, C15.2, C16.2, C17.2, C18.2, C19.2, C20.1, C21.2, C22.1, C24.1, C25.1, L2.2, LDR.2, LED2.2, R7.1, R11.2, R13.2, R16.1, SV1.4, U1.4, U2.2, U2.3, U3.VDD, U4.3, U4.8, U4.13, U7.A3, U7.B1, U8.5, U9.5, U10.19, U10.20, U10.46, U10.47, U10.49, U$7.5
ANT: L1.1, U10.15
BUZZ+: BUZZ.+, U10.41
BUZZ-: BUZZ.-, U10.40
ENABLE: R9.1, U$7.1
GND: BAT.-, C1.1, C2.1, C5.2, C6.1, C7.1, C8.1, C9.-, C10.1, C11.2, C12.1, C13.1, C14.1, C15.1, C16.1, C17.1, C18.1, C19.1, C20.2, C21.1, C22.2, C23.2, C24.2, C25.2, R2.1, R6.2, R12.2, S1.1, S2.1, SV1.1, U1.6, U1.GND1, U1.GND2, U2.7, U3.7, U3.GND, U4.1, U4.9, U4.11, U4.15, U4.17, U4.18, U6.2, U7.A1, U7.A2, U7.C1, U8.2, U9.2, U9.4, U9.6, U10.14, U10.16, U10.17, U10.18, U10.21, U10.29, U10.30, U10.37, U10.45, U10.48, U10.50, U10.55, U10.56, U10.57, U10.58, U10.59, U10.60, U10.61, U10.62, U10.63, U10.64, U10.65, U10.66, U10.67, U$7.2, X1.GND, X1.MT1, X1.MT2
LDR: LDR.1, R12.1, U10.1
MCU_USB_DM: R8.1, U10.52
MCU_USB_DP: R3.1, U10.51
MIC: C4.1, R5.1, U8.1, U10.2
MISO: U1.7, U10.25
MOSI: U1.3, U10.23
unnamed: ANT1.1, C11.1, L1.2
unnamed: C3.2, U9.1
unnamed: L2.1, U$7.3
unnamed: R2.2, U6.5
unnamed: LED.C, R1.1
unnamed: R1.2, U6.1
unnamed: C3.1, R4.2
unnamed: C4.2, R4.1, R5.2, U8.4
unnamed: C5.1, R6.1, R7.2, U8.3
unnamed: C14.2, U4.20
unnamed: R13.1, U7.C2
unnamed: C12.2, U4.10
unnamed: R8.2, X1.D-
unnamed: R3.2, X1.D+
unnamed: LED2.3, R14.1
unnamed: LED2.4, R10.1
unnamed: LED2.1, R15.1
PBL: S1.3, U10.43
PBR: S2.3, U10.44
RGB_BLUE: R14.2, U10.6
RGB_GREEN: R10.2, U10.7
RGB_RED: R15.2, U10.8
RX: SV1.3, U10.38
SCK: U1.5, U10.24
SCL: R11.1, U2.5, U3.SCK, U4.23, U7.B3, U10.5
SDA: R16.2, U2.6, U3.DATA, U4.24, U7.C3, U10.4
SD_CD: U1.CD, U10.42
SD_CS: U1.2, U10.22
TX: SV1.2, U10.39
UVCC: C1.2, D1.ANODE, LED.A, U6.4, X1.VBUS
VBAT: BAT.+, C2.2, C23.1, D1.CATHODE, R9.2, SW.1, SW.2, U6.3, U10.28, U$7.4

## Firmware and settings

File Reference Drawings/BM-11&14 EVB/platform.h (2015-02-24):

/*
 * Copyright 2012, Broadcom Corporation
 * All Rights Reserved.
 *
 * This is UNPUBLISHED PROPRIETARY SOURCE CODE of Broadcom Corporation;
 * the contents of this file may not be disclosed to third parties, copied
 * or duplicated in any form, in whole or in part, without the prior
 * written permission of Broadcom Corporation.
 */
#pragma once

#ifdef __cplusplus
extern "C"
{
#endif

/******************************************************
 *                      Macros
 ******************************************************/

/******************************************************
 *                    Constants
 ******************************************************/

/******************************************************
 *                   Enumerations
 ******************************************************/

/*
BCMUSI14 platform pin definitions ...
+----------------------------------------------------------------------------------------+
|Pin |  Pin Name on    |    Module     | STM32| Peripheral  |    Board     | Peripheral  |
| #  |     Module      |  GPIO Alias   | Port | Available   |  Connection  |   Alias     |
|----+-----------------+---------------+------+-------------+--------------+-------------|
| 40 | MICRO_GPIO1     | WICED_GPIO_1  | B  0 | ADC12_IN8   |              |             |
|    |                 |               |      | GPIO        |              |             |
|    |                 |               |      | TIM1_CH2_N  |              |             |
|    |                 |               |      | TIM3_CH3    |              |             |
|    |                 |               |      | TIM8_CH2N   |              |             |
|----+-----------------+---------------+------+-------------+--------------+-------------|
| 41 | MICRO_GPIO2     | WICED_GPIO_2  | B  1 | ADC12_IN9   |              |             |
|    |                 |               |      | GPIO        |              |             |
|    |                 |               |      | TIM3_CH4    |              |             |
|    |                 |               |      | TIM8_CH3N   |              |             |
|    |                 |               |      | TIM1_CH3N   |              |             |
|----+-----------------+---------------+------+-------------+--------------+-------------|
| 42 | MICRO_GPIO3     | WICED_GPIO_3  | C  0 | ADC123_IN11 |              |             |
|    |                 |               |      | GPIO        |              |             |
|----+-----------------+---------------+------+-------------+--------------+-------------|
| 33 | TESTMODE        | WICED_GPIO_4  | A  8 | I2C3_SCL    |              |             |
|    |                 |               |      | GPIO        |              |             |
|    |                 |               |      | TIM1_CH1    |              |             |
|    |                 |               |      | USART1_CK   |              |             |
|----+-----------------+---------------+------+-------------+--------------+-------------|
| 43 | MICRO_GPIO5     | WICED_GPIO_5  | C  3 | ADC123_IN13 |              |             |
|    |                 |               |      | GPIO        |              |             |
|    |                 |               |      | I2S2_SD     |              |             |
|    |                 |               |      | SPI2_MOSI   |              |             |
|----+-----------------+---------------+------+-------------+--------------+-------------|
| 44 | MICRO_GPIO6     | WICED_GPIO_6  | C  4 | ADC12_IN14  |              |             |
|    |                 |               |      | GPIO        |              |             |
|----+-----------------+---------------+------+-------------+--------------+-------------|
| 45 | MICRO_GPIO7     | WICED_GPIO_7  | B  5 | GPIO        |              |             |
|    |                 |               |      | I2C1_SMBA   |              |             |
|    |                 |               |      | I2S3_SD     |              |             |
|    |                 |               |      | SPI1_MOSI   |              |             |
|    |                 |               |      | SPI3_MOSI   |              |             |
|    |                 |               |      | TIM3_CH2    |              |             |
|----+-----------------+---------------+------+-------------+--------------+-------------|
| 46 | MICRO_GPIO8     | WICED_GPIO_8  | C  7 | GPIO        |              |             |
|    |                 |               |      | I2S3_MCK    |              |             |
|    |                 |               |      | TIM8_CH2    |              |             |
|    |                 |               |      | TIM3_CH2    |              |             |
|----+-----------------+---------------+------+-------------+--------------+-------------|
| 47 | MICRO_GPIO9     | WICED_GPIO_9  | C 13 | GPIO        |              |             |
|    |                 |               |      | RTC_AF1     |              |             |
|----+-----------------+---------------+------+-------------+--------------+-------------|
| 35 | MICRO_I2C1_SCL  | WICED_GPIO_10 | B  6 | GPIO        | LED D2       |             |
|    |                 |               |      | TIM4_CH1    |              | WICED_PWM_1 |
|    |                 |               |      | I2C1_SCL    |              |             |
|----+-----------------+---------------+------+-------------+--------------+-------------|
| 36 | MICRO_I2C1_SDA  | WICED_GPIO_11 | B  7 | GPIO        | LED D1       |             |
|    |                 |               |      | TIM4_CH2    |              | WICED_PWM_2 |
|    |                 |               |      | I2C1_SDA    |              |             |
|----+-----------------+---------------+------+-------------+--------------+-------------|
| 48 | MICRO_GPIO12    | WICED_GPIO_12 | C  1 | ADC123_IN11 |              |             |
|    |                 |               |      | GPIO        |              |             |
|----+-----------------+---------------+------+-------------+--------------+-------------|
| 49 | MICRO_GPIO13    | WICED_GPIO_13 | C  2 | ADC123_IN12 |              |             |
|    |                 |               |      | GPIO        |              |             |
|    |                 |               |      | SPI2_MISO   |              |             |
|----+-----------------+---------------+------+-------------+--------------+-------------|
| 50 | MICRO_GPIO14    | WICED_GPIO_14 | C  5 | ADC12_IN15  |              |             |
|    |                 |               |      | GPIO        |              |             |
|----+-----------------+---------------+------+-------------+--------------+-------------|
| 51 | MICRO_JTAG_TRST | WICED_GPIO_15 | B  4 | GPIO        |              |             |
|    |                 |               |      | NJTRST      |              |             |
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

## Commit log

2015-02-08 Initial Commit
    Added all files
    [eNode_Spark.brd, eNode_Spark.sch, photon_at7020_2.brd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]
2015-02-24 Major commit
    Updated rev from 3.0 to 3.1
    [V3.X BOM.xlsx, eNode_Spark.brd, eNode_Spark.sch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]
2015-02-24 Updated Traces
    Updated traces near top of BM-09
    [eNode_Spark.brd]
2015-02-25 Fully Routed
    Fully Routed, DRC checked, Gerbers generated
    [eNode_Spark.GBL, eNode_Spark.GBO, eNode_Spark.GBP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]

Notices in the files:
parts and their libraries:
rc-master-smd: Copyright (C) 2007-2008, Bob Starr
